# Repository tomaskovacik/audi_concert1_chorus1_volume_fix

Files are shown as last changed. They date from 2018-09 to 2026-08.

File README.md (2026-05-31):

> ## ⚠️ v2.0.0 — Important notice
>
> **Firmware v2.0.0 is only suitable for HWv5 boards.** It will NOT work correctly on older hardware revisions (v1–v4).
>
> This release is currently **under real-life / daily-use testing**. If you experience issues, please open a [GitHub issue](https://github.com/tomaskovacik/audi_concert1_chorus1_volume_fix/issues).
>
> ### What changed in v2.0.0 (not in release notes — no PRs were used)
>
> - **Switched to official STMicroelectronics STM32 Arduino core** (replaces Roger Clark's libmaple/stm32duino community core)
> - **Hardware SPI** used for front-panel communication (via STM32 core SPI peripheral)
> - **FlexWire** software I2C library used for TDA7342 volume chip communication on PB10/PB11  
>   (STM32F103C6 has only one I2C peripheral; hardware I2C2 does not exist on this chip)
> - **Persistent config** saved to last flash page (volume level, GALA, TA) — replaces EEPROM emulation from older cores
> - **GALA** (speed-dependent volume) support via VSS pulse timing on PB5
> - **CI** updated to build and release firmware binary automatically on git tags

Software and hardware to fix volume problem on audi concert1/chorus1 units made by blaupunkt. More about this problem in [this](https://github.com/tomaskovacik/audi_concert1_chorus1_volume_fix/wiki/Problem-of-Some-AUDI-Chorus-and-AUDI-Concert-Autoradio-Models,-or-%22Delayed-Action-Mine%22-from-Blaupunkt-Company) wiki page which is copy from [here](https://web.archive.org/web/20071017195907/http://erta.ru/review/chorus-problem_eng.shtml).

#### Compatible radios:

These are 100% compatible, manufactured by Blaupunkt:
```
Audi Chorus - 7 646 243 380 (4B0 035 152)
Audi Chorus A8 - 7 647 243 380
Audi Concert - 7 646 248 380 (4B0 035 186)
Audi Concert A8 - 7 647 248 380 (4D0 035 186A)
Audi Concert Navi - 7 647 249 380 (4B0 035 186B)
AUDI	CONCERT TT AUZ1Z3	7 648 244 380 (4B0 035 186D)
```
Maybe for these, drop me a message with pictures of radio from outside and inside, and I can check if your radio is compatible with this module:
```
AUDI	CHORUS A3	7 640 251 380
AUDI	CHORUS A8	7 648 243 380
AUDI	CHORUS AUZ1Z2	7 647 245 380   4B0 035 152A
AUDI	CHORUS M4 AUZ1Z2	7 648 245 380   4B0 035 152B
AUDI	CHORUS M4 AUZ1Z2	7 648 245 380   4B0 035 152B
AUDI	CONCERT A8	7 648 248 380
AUDI	CONCERT M4 AUZ1Z3	7 648 247 380   4B0 035 186C
```
#### Not compatible radios

Audio Concert made by Panasonic/Matsushita (8L0 035 186A, possible other codes ).This radio from this manufacturer did not have problems with volume (if it has, the problem is in volume rotary encoder)

There are other radios manufactured by Blaupunkt called Audi Concert Plus, which are not compatible:
```
AUDI	CONCERT PLUS AUZ1Z3	7 649 246 380   4B0 035 186E
AUDI	CONCERT PLUS A8 AUZ1Z3	7 649 249 380   4D0 035 186F
```
These use a different design and so are not compatible with this module. I never read that these radios did have a volume problem. If there is one then it is most likely a problem with volume rotary encoder.

#### Issues
Known issues <a href="https://github.com/tomaskovacik/audi_concert1_chorus1_volume_fix/issues">are here</a>

#### Video
Module in action: 

#### Schematics:

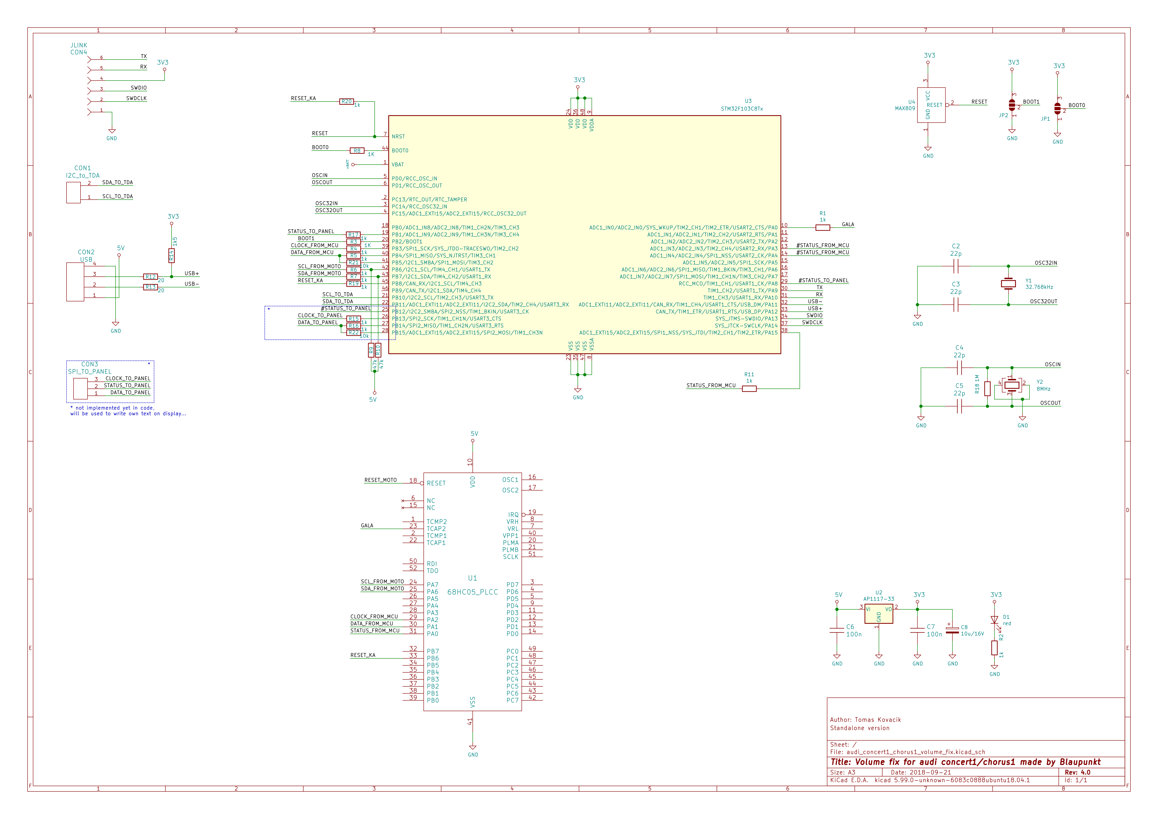
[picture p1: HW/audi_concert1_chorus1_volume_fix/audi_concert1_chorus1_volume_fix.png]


Schematics in <a href="https://github.com/tomaskovacik/audi_concert1_chorus1_volume_fix/blob/master/HW/audi_concert1_chorus1_volume_fix/audi_concert1_chorus1_volume_fix.pdf">pdf</a>.

Assemble plan for latest v5 is <a href="https://tomaskovacik.github.io/audi_concert1_chorus1_volume_fix/HW/audi_concert1_chorus1_volume_fix/bom_v5/ibom.html">here</a>. Components with value prefi NP_ are not required (not populated). These are there for future features. 1k_GALA resistor has to be populated if SW with <a href="https://github.com/tomaskovacik/audi_concert1_chorus1_volume_fix/blob/gala/SW/audi_volume_fix_stm32/audi_volume_fix_stm32.ino">gala</a> support is used (SW from gala branch). AP for old v1 hw is <a href="https://raw.githubusercontent.com/tomaskovacik/audi_concert1_chorus1_volume_fix/master/HW/audi_concert1_chorus1_volume_fix/assemble_plan1_0.png">here</a>.

Pictures of finished product:

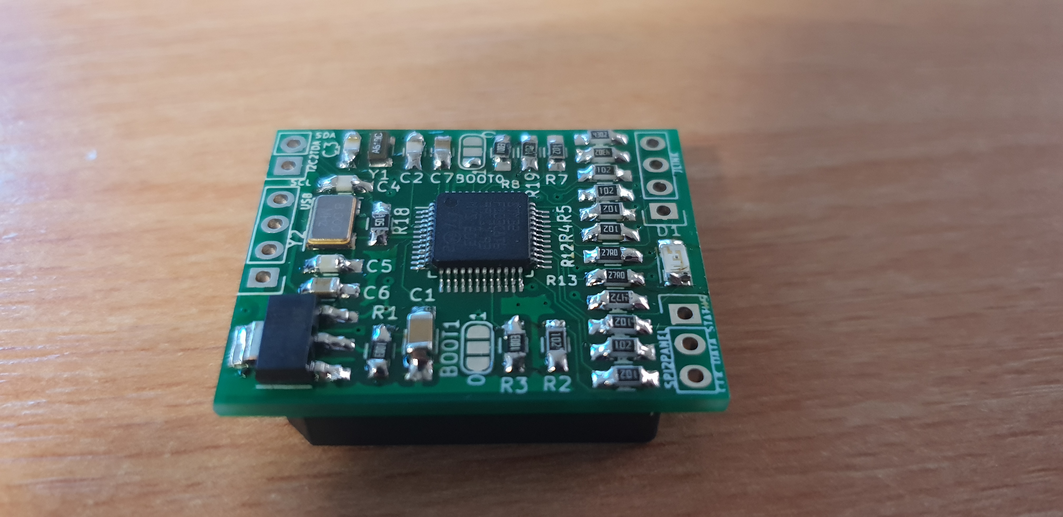
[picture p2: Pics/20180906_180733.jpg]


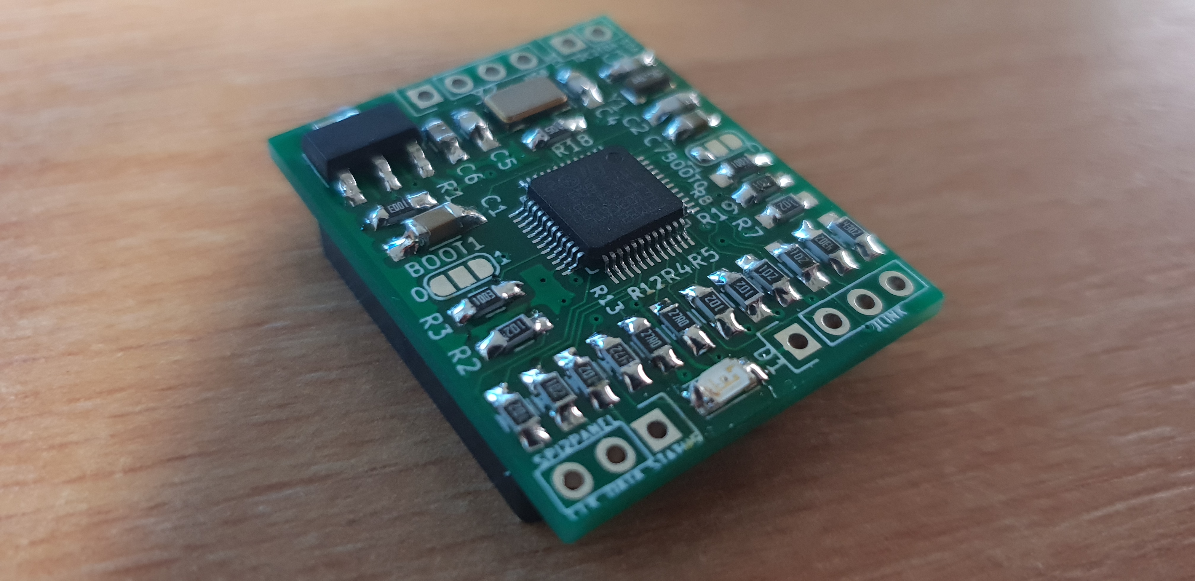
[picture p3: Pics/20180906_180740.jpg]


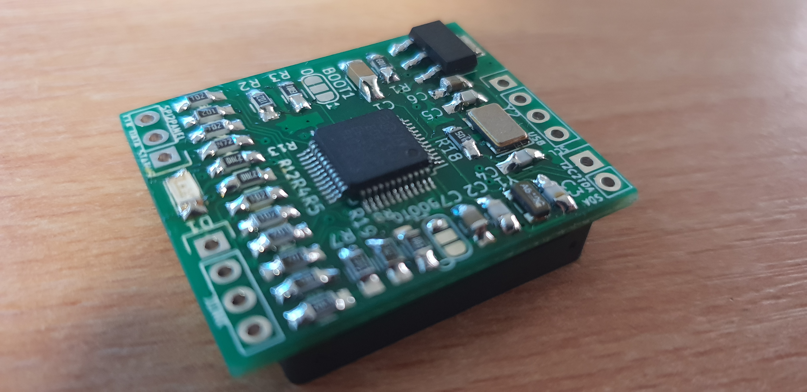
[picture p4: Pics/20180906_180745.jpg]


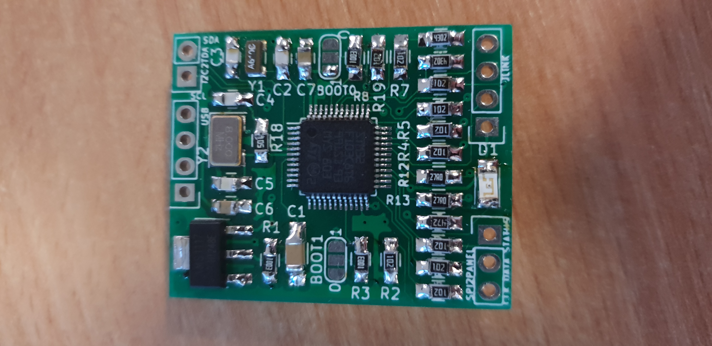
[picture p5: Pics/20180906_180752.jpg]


Bottom side, with PLCC52 socket, inside part of pastic need to be cut:

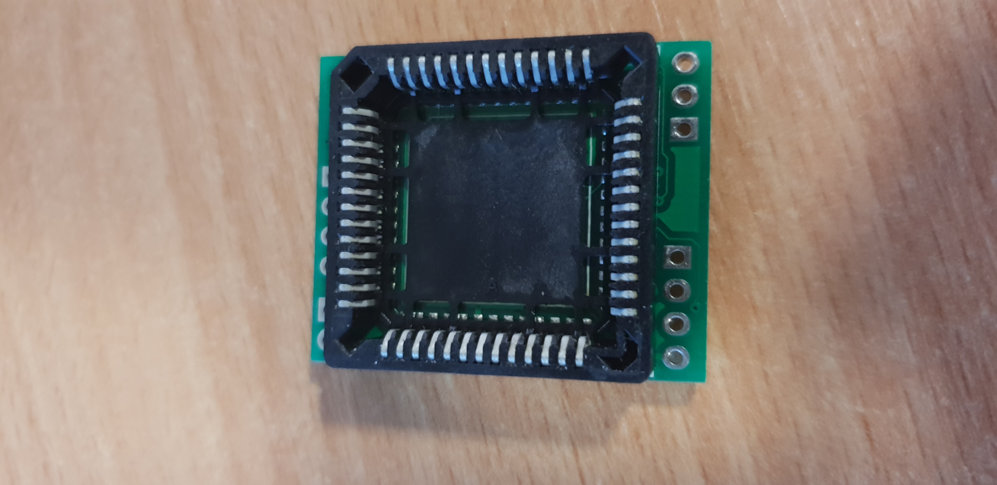
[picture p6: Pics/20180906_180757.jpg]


Upper side, with comments to sockets

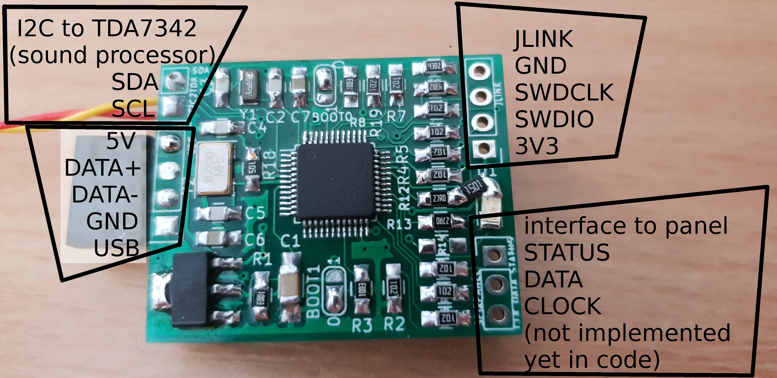
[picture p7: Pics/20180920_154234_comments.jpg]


How to wire it (currently without intefacing with front pannel)

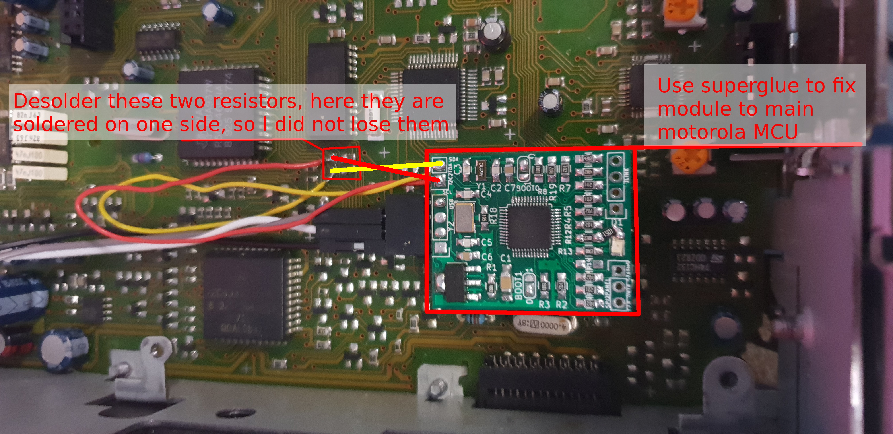
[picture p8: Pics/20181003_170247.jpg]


# COPYING

Everything is under GPLv3

# CONTRIBUTION

Contributions are welcome

# PCBs

PCBs are on sale also as whole product, kitt (PCB, soldered crystals, unsoldered preprogramed IC, pasives,PLCC52 socket)



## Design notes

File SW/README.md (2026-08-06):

# Firmware — Audi Concert1 / Chorus1 volume fix

STM32F103C6-based firmware that fixes the volume problem on Blaupunkt-made
Audi Concert 1 / Chorus 1 head units.  Target hardware: **HWv5**.

---

## Branches

| Branch | Description |
|---|---|
| `master` | Stable HWv5 firmware — passive SPI sniffer, GALA, flash config, serial decoder |
| `dual-spi-panel-bridge` | **WIP** — HWv5 man-in-the-middle bridge: SPI1 slave (MCU side) + SPI2 master (panel side); STM32 intercepts and forwards packets in both directions. Activate with `#define HWV5_BRIDGE`; omit for passive-sniff fallback. |
| `feature/eeprom-gala-isr-STM32CORE-sleep` | Deep sleep on displayRESET LOW — kept for reference, no real benefit with current HW |

---

## Building and flashing

### Dependencies

- Arduino IDE install at `/opt/arduino-nightly/`
- **Official STMicroelectronics STM32 core 2.12+** installed via Arduino Boards Manager:
  - Board URL: `https://github.com/stm32duino/BoardManagerFiles/raw/main/package_stmicroelectronics_index.json`
  - Package: `STMicroelectronics:stm32` — select board **Generic STM32F1 series → BluePill F103C6**
  - Tools installed automatically: `xpack-arm-none-eabi-gcc 14.2.1-1.1`, `STM32Tools 2.4.0`, `xpack-openocd 0.12.0-6`
- **FlexWire** library (software I2C) — install via Arduino Library Manager or from source

### Build targets

```bash
cd SW/audi_volume_fix_stm32
make          # compile only
make upload   # compile + flash via ST-Link (OpenOCD)
make serial   # open serial monitor (115200 baud)
make clean    # remove build artefacts
```

### Flashing

Flashing uses **OpenOCD** (bundled with the official core) via ST-Link:

```bash
make upload
```

No separate `st-flash` installation needed.

---

## Serial decoder (`SW/decoder.py`)

Reads the firmware's serial output and prints human-readable labels.

```bash
# From USB serial port (default 115200 baud):
python3 decoder.py /dev/ttyUSB0

# Custom baud:
python3 decoder.py /dev/ttyUSB0 9600

# Pipe from file or socat:
python3 decoder.py --stdin < log.txt

# Append raw hex [XX XX ...] to every decoded line:
python3 decoder.py --debug /dev/ttyUSB0
python3 decoder.py --debug --stdin
```

Output prefixes:

| Prefix | Colour | Meaning |
|---|---|---|
| `SPI` | Yellow | Front-panel → MCU SPI packet (decoded) |
| `BTN` | Red | Button / knob event |
| `TDA` | Green | STM32 → TDA7342 I2C command (decoded) |

---

## Configuration (`feature/eeprom-gala-isr-STM32CORE`)

### Stored values

Configuration is saved in the **last 1 KB page of STM32 flash** (`0x8007C00`).
Three values are persisted:

| Field | Range | Default | Meaning |
|---|---|---|---|
| `vol` | 1–5 | 3 | Start volume level at power-on |
| `gala` | 0–5 | 0 | GALA speed-volume aggressiveness (0 = off) |
| `ta` | 1–5 | 3 | TA (traffic announcement) level |

The page is protected by 3 magic bytes and a CRC (`vol+gala+ta`).
After a CRC pass each field is range-checked; out-of-range fields fall
back to their default individually (guards against partial flash corruption).

### Start volume (`vol`)

`vol` is a **fixed level index**, not a relative offset.  It maps to an
absolute TDA7342 register value via a lookup table:

| `vol` | I2C hex | Approx. level |
|---|---|---|
| 1 | `0x56` | quietest |
| 2 | `0x52` | |
| 3 | `0x4E` | default |
| 4 | `0x4A` | |
| 5 | `0x46` | loudest |

Each step is 4 register counts ≈ **2 dB**.

### GALA speed-volume (`gala`)

GALA (*Geschwindigkeitsabhängige Lautstärkeautomatik* — speed-dependent automatic
volume) automatically raises the volume as speed increases to compensate for rising
road and wind noise, keeping perceived audio level consistent.

| Level | Sensitivity | Description |
|---|---|---|
| `0` | Off | Volume stays exactly where you set it — GALA disabled |
| `1` | Lowest | Subtle boost; only noticeable at high highway speeds |
| `2` | Low | Mild adjustment for relaxed highway driving |
| `3` | Medium | Factory sweet spot for a stock Audi cabin; smooth steps with normal acceleration |
| `4` | High | More aggressive; volume rises at lower speed thresholds |
| `5` | Highest | Aggressively boosts volume starting at low speeds |

When `gala > 0` the firmware measures a VSS (vehicle speed signal) pulse width on
**PB5** (TIM3_CH2, tied with PB4/TIM3_CH1). Speed is derived from the pulse half-period:

```
speed_km/h = 1 000 000 / (2 × avg_pulse_width_µs)
```

An 8-sample rolling average suppresses µs-level jitter.

GALA level controls the base speed threshold at which volume starts rising:

| `gala` | Base threshold |
|---|---|
| 1 | 100 km/h |
| 2 | 85 km/h |
| 3 | 70 km/h |
| 4 | 55 km/h |
| 5 | 40 km/h |

Above the base threshold volume steps **up** by 1 and loudness steps **down**
every additional 30 km/h band.  Slowing down reverses the corrections.

Hardware: BC558 PNP high-side driver on the radio PCB drives the GALA line.
STM32 PB5 is connected in parallel with HC05 pin 23 via a 1 kΩ series resistor.
`INPUT_PULLDOWN` is used so the pin reads LOW cleanly when the transistor is OFF.

### Setting config via serial commands

With `USE_SERIAL` enabled, send commands over UART1 (115200 baud):

| Command | Effect |
|---|---|
| `s1` … `s5` | Set start volume level |
| `g0` … `g5` | Set GALA level (0 = off) |
| `w` | Save current config to flash |

### Setting config via radio menu (display auto-save)

The firmware sniffs `0x9A 0x58` display packets sent by the radio when the
user navigates the **settings menu** (accessed with the TP button).
Config is saved to flash automatically as the user scrolls:

| Radio display | Saved value |
|---|---|
| `VOL  1` … `VOL  5` | `vol` = 1–5 |
| `GALA 1` … `GALA 5` | `gala` = 1–5 |
| `GALA OFF` | `gala` = 0 |
| `TA 1` … `TA 5` | `ta` = 1–5 |

### Debug serial output

When `USE_SERIAL` is defined, key events print with these prefixes:

| Prefix | When |
|---|---|
| `CFG_LOAD: vol=X gala=X ta=X` | Config read from flash at startup |
| `CFG_PANEL: vol/gala/ta=X` | Value parsed from radio display packet |
| `CFG_SAVE: OK/FAIL vol=X gala=X ta=X` | Flash write result |
| `GALA_SPEED: prev->new km/h base_thr=X` | Speed change detected |
| `GALA_VOL: UP/DOWN band=X thr=X vol=0xXX` | Volume step applied |
| `GALA_LOUD: UP/DOWN band=X thr=X loud=0xXX` | Loudness step applied |

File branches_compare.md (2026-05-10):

# Branch Comparison Summary

## `devel` vs `master` — Branch Comparison

The `devel` branch is ahead of `master` with significant changes to `SW/audi_volume_fix_stm32/audi_volume_fix_stm32.ino` and one new binary file.

## 📁 Files Changed

- `SW/audi_volume_fix_stm32/audi_volume_fix_stm32.ino` — Major changes (details below)
- `gala_on_V1.png` (new file) — A new image added (likely documentation for GALA on V1 board)

## 🔧 Key Code Changes in `devel`

### 1. EEPROM Support Added

- Includes `<EEPROM.h>` and defines EEPROM layout (`EEPROM_PAGE0_BASE`, `EEPROM_PAGE1_BASE`, `EEPROM_PAGE_SIZE`)
- New EEPROM keys: `EEPROM_GALA`, `EEPROM_VOL`, `EEPROM_TA`, `EEPROM_CR1`–`CR4`
- New functions: `checkEEPROM()`, `getGalaEeprom()`, `getVolEeprom()`, `getTaEeprom()`, `saveGalaEeprom()`, `saveVolEeprom()`, `saveTaEeprom()`
- Settings (GALA, VOL, TA) are now persisted across power cycles

### 2. GALA (Speed-Dependent Volume) Feature

- New GALA pin defined (`PA14` for V1 board, `PA0` for V2)
- Interrupt-driven speed sensing using Timer2 — `galaRising()` / `galaFalling()` ISRs
- Speed is calculated from pulse timing (`captime`)
- Volume and loudness are automatically adjusted as speed increases/decreases in 30 km/h steps (up to 300+ km/h range)
- `getGalaStartSpeed()` computes the activation threshold from EEPROM

### 3. `set_volume()` renamed to `send_volume()`

- `set_loudness()` now only calculates the loudness value
- New `send_loudness()` function handles sending it over I²C
- Calls to `set_volume()` replaced throughout with `send_volume()` + `send_loudness()` pairs
- Volume packet sending logic refactored (removed duplicate `set_loudness()` calls inside the loop)

### 4. Start Volume from EEPROM

- `start_volume` now initialized from `setStartVolumeFromEeprom()` (maps 1–5 → hex values)
- Was hardcoded `0x82`; now defaults to `0x4E`
- Also re-applied on display reset event

### 5. I²C Dump Mode Improvements

- `dumpI2cDataAndDoNotFix` renamed to `dumpI2cData` — it's now independent from the fix logic (both can run simultaneously)
- `dump_i2c_data()` output format improved: `I2c data: [ xx xx ]`

### 6. Display Data Parsing for Settings

- Detects VOL/TA/GALA settings displayed on the panel and saves them to EEPROM automatically
  - e.g., `"VOL  X  "` → saves volume level, `"GALA X  "` → saves GALA setting

### 7. Code Style / Minor Fixes

- Fixed indentation of several `case` labels in `decode_button_push()`
- Miscellaneous whitespace and comment cleanup

## Summary Table

| Feature | `master` | `devel` |
|---|---|---|
| EEPROM persistence | ❌ | ✅ |
| GALA (speed-adaptive volume) | ❌ | ✅ |
| Start volume | Hardcoded `0x82` | From EEPROM (`0x4E` default) |
| Loudness sending | Inside `set_loudness()` | Separate `send_loudness()` |
| Dump mode decoupled from fix | ❌ | ✅ |
| Settings saved from display | ❌ | ✅ |

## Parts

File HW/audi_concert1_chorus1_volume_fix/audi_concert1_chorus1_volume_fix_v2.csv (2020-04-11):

Id | Designator | Package | Quantity | Designation | Supplier and ref
1 | R14 | R_0805_HandSoldering | 1 | 1k5
2 | R8,R3 | R_0805_HandSoldering | 2 | 100k
3 | R1,R20,R19,R17,R16,R15,R6,R5,R4,R11,R2,R7 | R_0805_HandSoldering | 12 | 1k
4 | U4 | SOT-23 | 1 | MAX809
5 | CON4 | Pin_Header_Straight_1x06 | 1 | JLINK
6 | BOOT0,BOOT1 | SolderJumper-3_P1.3mm_Open_RoundedPad1.0x1.5mm_NumberLabels | 2 | SolderJumper_3_Open
7 | CON3 | Pin_Header_Straight_1x03 | 1 | SPI_TO_PANEL
8 | CON2 | Pin_Header_Straight_1x04 | 1 | USB
9 | Y2 | Crystal_SMD_5032-4pin_5.0x3.2mm | 1 | 8MHz
10 | Y1 | Crystal_SMD_3215-2pin_3.2x1.5mm | 1 | 32.768kHz
11 | R18 | R_0805_HandSoldering | 1 | 1M
12 | R13,R12 | R_0805_HandSoldering | 2 | 20
13 | D1 | LED-1206 | 1 | LED
14 | CON1 | Pin_Header_Straight_1x02 | 1 | I2C_to_TDA
15 | C7,C6 | C_0805_HandSoldering | 2 | 100n
16 | C5,C4,C3,C2 | C_0805_HandSoldering | 4 | 22p
17 | U1 | PLCC-52_mirrored | 1 | 68HC05_PLCC
18 | U2 | AB2_SOT223 | 1 | AP1117-33
19 | R10,R9 | R_0805_HandSoldering | 2 | 47k
20 | C8 | TantalC_SizeA_EIA-3216_HandSoldering | 1 | 10u/16V
21 | U3 | LQFP-48_7x7mm_Pitch0.5mm | 1 | STM32F103C8Tx

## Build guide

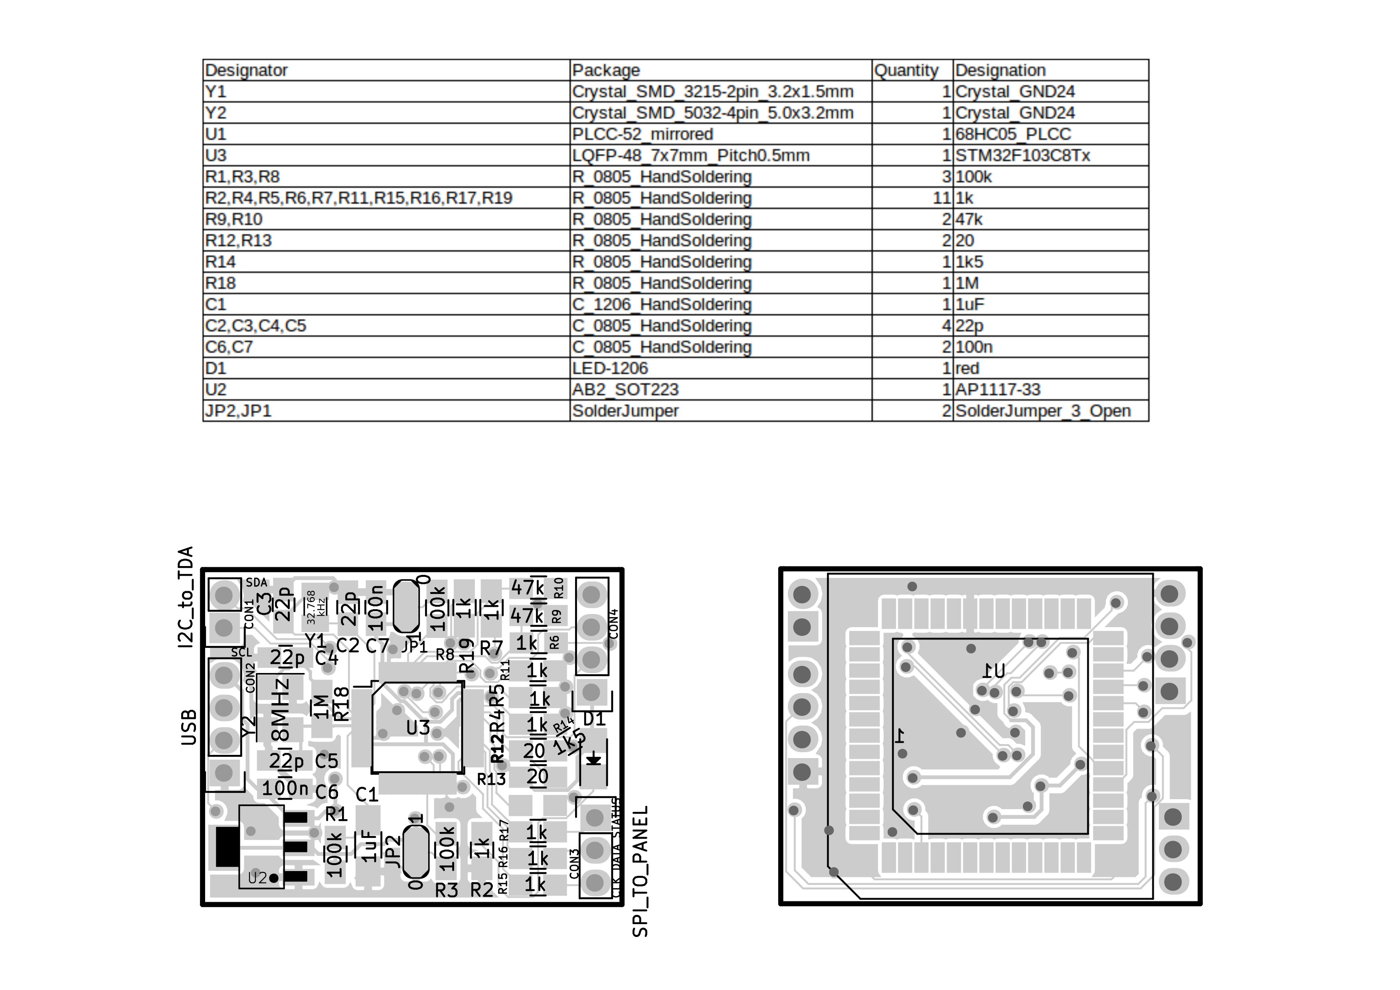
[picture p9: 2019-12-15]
HW/audi_concert1_chorus1_volume_fix/assemble_plan1_0.png

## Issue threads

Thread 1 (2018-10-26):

after restart of car treble and bass level is not set properly.

tomaskovacik, 2018-10-26:
after restart of car, looks like something did not catch up.... treble and bass level is not set properly, this need to by probably investigated more complexly to realize if we are sending something to soon, to fast
  or we just missing capture of something or we catch everything and just forget to send it to TDA???

tomaskovacik, 2019-03-22:
looks like fixed by b7195835907241808e6d238cddf0f1e86493aa1a

tomaskovacik, 2019-03-22:
on my concert it is still problem, but probably problem of MCU:

Reset HIGH
 uknown25

Speaker Attenuator left front: -3.75dB
Speaker Attenuator left rear: 0.00dB
Speaker Attenuator right front: -3.75dB
Speaker Attenuator left rear: 0.00dB
Bass: 0dB, Trebble: 0dB
Mute: Soft Mute with fast slope (I = Imax)
Zero Crossing Mute Off
160mV ZC Window Threshold (WIN = 00)
Symmetrical Bass Cut
Input selector: CD selected (0dB diferential input gain (IN3))

Memory: 0

LEDS:

display clear

Memory: 0

LEDS:
MODE
display clear
 uknown0

CD2 TR4
CD2 TR4
CD2 TR4
CD81 TR4
CD2 TR4
Loudness:  - 16.2500000000dB
Loudness:  - 15.0000000000dB
Loudness:  - 13.7500000000dB
Loudness:  - 12.5000000000dB
Loudness:  - 11.2500000000dB
Loudness:  - 10.0000000000dB
Loudness:  - 8.7500000000dB
Loudness:  - 7.5000000000dB
volume -59.06dB ( FD )
volume -58.43dB ( FB )
volume -57.81dB ( F9 )
volume -57.18dB ( F7 )
volume -56.56dB ( F5 )
volume -55.93dB ( F3 )
volume -55.31dB ( F1 )
volume -54.68dB ( EF )
volume -54.06dB ( ED )
volume -53.43dB ( EB )
volume -52.81dB ( E9 )
volume -52.18dB ( E7 )
volume -51.56dB ( E5 )
volume -50.93dB ( E3 )
volume -50.31dB ( E1 )
volume -49.68dB ( DF )
volume -49.06dB ( DD )
volume -48.43dB ( DB )
volume -47.81dB ( D9 )
volume -47.18dB ( D7 )
volume -46.56dB ( D5 )
volume -45.93dB ( D3 )
volume -45.31dB ( D1 )
volume -44.68dB ( CF )
volume -44.06dB ( CD )
volume -43.43dB ( CB )
volume -42.81dB ( C9 )
volume -42.18dB ( C7 )
volume -41.56dB ( C5 )
volume -40.93dB ( C3 )
volume -40.31dB ( C1 )
volume -39.68dB ( BF )
volume -39.06dB ( BD )
volume -38.43dB ( BB )
volume -37.81dB ( B9 )
volume -37.18dB ( B7 )
volume -36.56dB ( B5 )
volume -35.93dB ( B3 )
volume -35.31dB ( B1 )
volume -34.68dB ( AF )
volume -34.06dB ( AD )
volume -33.43dB ( AB )
volume -32.81dB ( A9 )
volume -32.18dB ( A7 )
volume -31.56dB ( A5 )
volume -30.93dB ( A3 )
volume -30.31dB ( A1 )
volume -29.68dB ( 9F )
volume -29.06dB ( 9D )
volume -28.43dB ( 9B )
volume -27.81dB ( 99 )
volume -27.18dB ( 97 )
volume -26.56dB ( 95 )
volume -25.93dB ( 93 )
volume -25.31dB ( 91 )
volume -24.68dB ( 8F )
volume -24.06dB ( 8D )
volume -23.43dB ( 8B )
volume -22.81dB ( 89 )
volume -22.18dB ( 87 )
volume -21.56dB ( 85 )
volume -20.93dB ( 83 )
volume -20.31dB ( 81 )
volume -19.68dB ( 7F )
volume -19.06dB ( 7D )
volume -18.43dB ( 7B )
volume -17.81dB ( 79 )
volume -17.18dB ( 77 )
volume -16.56dB ( 75 )
volume -15.93dB ( 73 )
volume -15.31dB ( 71 )
volume -14.68dB ( 6F )
volume -14.06dB ( 6D )
volume -13.43dB ( 6B )
volume -12.81dB ( 69 )
volume -12.18dB ( 67 )
volume -11.56dB ( 65 )
volume -10.93dB ( 63 )
volume -10.31dB ( 61 )
volume -9.68dB ( 5F )
volume -9.06dB ( 5D )
volume -8.43dB ( 5B )
volume -7.81dB ( 59 )
volume -7.18dB ( 57 )
volume -6.56dB ( 55 )
volume -5.93dB ( 53 )
volume -5.31dB ( 51 )
volume -4.68dB ( 4F )
volume -4.06dB ( 4D )
volume -3.43dB ( 4B )
volume -2.81dB ( 49 )
volume -2.18dB ( 47 )
volume -1.56dB ( 45 )
volume -0.93dB ( 43 )
volume -0.31dB ( 41 )
volume 0.32dB ( 3F )
volume 0.94dB ( 3D )
volume 1.57dB ( 3B )
volume 2.19dB ( 39 )
volume 2.50dB ( 38 )
Mute: Zero Crossing Mute Off
160mV ZC Window Threshold (WIN = 00)
Symmetrical Bass Cut
Speaker Attenuator left front: -3.75dB
Speaker Attenuator left rear: 0.00dB
Speaker Attenuator right front: -3.75dB
Speaker Attenuator left rear: 0.00dB
Bass: 0dB, Trebble: 0dB
Loudness:  - 8.7500000000dB
Loudness:  - 10.0000000000dB
Loudness:  - 11.2500000000dB
Loudness:  - 12.5000000000dB
Loudness:  - 13.7500000000dB
Loudness:  - 15.0000000000dB
Loudness:  - 16.2500000000dB
Loudness:  - 17.5000000000dB
volume 1.88dB ( 3A )
volume 1.25dB ( 3C )
volume 0.63dB ( 3E )
volume 0.00dB ( 40 )
volume -0.62dB ( 42 )
volume -1.25dB ( 44 )
volume -1.87dB ( 46 )
volume -2.50dB ( 48 )
volume -3.12dB ( 4A )
volume -3.75dB ( 4C )
volume -4.37dB ( 4E )
volume -5.00dB ( 50 )
volume -5.62dB ( 52 )
volume -6.25dB ( 54 )
volume -6.87dB ( 56 )
volume -7.50dB ( 58 )
volume -8.12dB ( 5A )
volume -8.75dB ( 5C )
volume -9.37dB ( 5E )
volume -10.00dB ( 60 )
volume -10.62dB ( 62 )
volume -11.25dB ( 64 )
volume -11.87dB ( 66 )
volume -12.50dB ( 68 )
volume -13.12dB ( 6A )
volume -13.75dB ( 6C )
volume -14.37dB ( 6E )
volume -15.00dB ( 70 )
volume -15.62dB ( 72 )
volume -16.25dB ( 74 )
volume -16.87dB ( 76 )
volume -17.50dB ( 78 )
volume -18.12dB ( 7A )
volume -18.75dB ( 7C )
volume -19.37dB ( 7E )
volume -20.00dB ( 80 )
volume -20.62dB ( 82 )
volume -21.25dB ( 84 )
volume -21.87dB ( 86 )
volume -22.50dB ( 88 )
volume -23.12dB ( 8A )
volume -23.75dB ( 8C )
volume -24.37dB ( 8E )
volume -25.00dB ( 90 )
volume -25.62dB ( 92 )
volume -26.25dB ( 94 )
volume -26.87dB ( 96 )
volume -27.50dB ( 98 )
volume -28.12dB ( 9A )
volume -28.75dB ( 9C )
volume -29.37dB ( 9E )
volume -30.00dB ( A0 )
volume -30.62dB ( A2 )
volume -31.25dB ( A4 )
volume -31.87dB ( A6 )
volume -32.50dB ( A8 )
volume -33.12dB ( AA )
volume -33.75dB ( AC )
volume -34.37dB ( AE )
volume -35.00dB ( B0 )
volume -35.62dB ( B2 )
volume -36.25dB ( B4 )
volume -36.87dB ( B6 )
volume -37.50dB ( B8 )
volume -38.12dB ( BA )
volume -38.75dB ( BC )
volume -39.37dB ( BE )
volume -40.00dB ( C0 )
volume -40.62dB ( C2 )
volume -41.25dB ( C4 )
volume -41.87dB ( C6 )
volume -42.50dB ( C8 )
volume -43.12dB ( CA )
volume -43.75dB ( CC )
volume -44.37dB ( CE )
volume -45.00dB ( D0 )
volume -45.62dB ( D2 )
volume -46.25dB ( D4 )
volume -46.87dB ( D6 )
volume -47.50dB ( D8 )
volume -48.12dB ( DA )
volume -48.75dB ( DC )
volume -49.37dB ( DE )
volume -50.00dB ( E0 )
volume -50.62dB ( E2 )
volume -51.25dB ( E4 )
volume -51.87dB ( E6 )
volume -52.50dB ( E8 )
volume -53.12dB ( EA )
volume -53.75dB ( EC )
volume -54.37dB ( EE )
volume -55.00dB ( F0 )
volume -55.62dB ( F2 )
volume -56.25dB ( F4 )
volume -56.87dB ( F6 )
volume -57.50dB ( F8 )
volume -58.12dB ( FA )
volume -58.75dB ( FC )
volume -59.37dB ( FE )
volume -59.68dB ( FF )
Mute: Soft Mute with fast slope (I = Imax)
Zero Crossing Mute Off
160mV ZC Window Threshold (WIN = 00)
Symmetrical Bass Cut
CD2 TR4
Loudness:  - 16.2500000000dB
Loudness:  - 15.0000000000dB
Loudness:  - 13.7500000000dB
Loudness:  - 12.5000000000dB
Loudness:  - 11.2500000000dB
Loudness:  - 10.0000000000dB
Loudness:  - 8.7500000000dB
Loudness:  - 7.5000000000dB
volume -59.06dB ( FD )
volume -58.43dB ( FB )
volume -57.81dB ( F9 )
volume -57.18dB ( F7 )
volume -56.56dB ( F5 )
volume -55.93dB ( F3 )
volume -55.31dB ( F1 )
volume -54.68dB ( EF )
volume -54.06dB ( ED )
volume -53.43dB ( EB )
volume -52.81dB ( E9 )
volume -52.18dB ( E7 )
volume -51.56dB ( E5 )
volume -50.93dB ( E3 )
volume -50.31dB ( E1 )
volume -49.68dB ( DF )
volume -49.06dB ( DD )
volume -48.43dB ( DB )
volume -47.81dB ( D9 )
volume -47.18dB ( D7 )
volume -46.56dB ( D5 )
volume -45.93dB ( D3 )
volume -45.31dB ( D1 )
volume -44.68dB ( CF )
volume -44.06dB ( CD )
volume -43.43dB ( CB )
volume -42.81dB ( C9 )
volume -42.18dB ( C7 )
volume -41.56dB ( C5 )
volume -40.93dB ( C3 )
volume -40.31dB ( C1 )
volume -39.68dB ( BF )
volume -39.06dB ( BD )
volume -38.43dB ( BB )
volume -37.81dB ( B9 )
volume -37.18dB ( B7 )
volume -36.56dB ( B5 )
volume -35.93dB ( B3 )
volume -35.31dB ( B1 )
volume -34.68dB ( AF )
volume -34.06dB ( AD )
volume -33.43dB ( AB )
volume -32.81dB ( A9 )
volume -32.18dB ( A7 )
volume -31.56dB ( A5 )
volume -30.93dB ( A3 )
volume -30.31dB ( A1 )
volume -29.68dB ( 9F )
volume -29.06dB ( 9D )
volume -28.43dB ( 9B )
volume -27.81dB ( 99 )
volume -27.18dB ( 97 )
volume -26.56dB ( 95 )
volume -25.93dB ( 93 )
volume -25.31dB ( 91 )
volume -24.68dB ( 8F )
volume -24.06dB ( 8D )
volume -23.43dB ( 8B )
volume -22.81dB ( 89 )
volume -22.18dB ( 87 )
volume -21.56dB ( 85 )
volume -20.93dB ( 83 )
volume -20.31dB ( 81 )
volume -19.68dB ( 7F )
volume -19.06dB ( 7D )
volume -18.43dB ( 7B )
volume -17.81dB ( 79 )
volume -17.18dB ( 77 )
volume -16.56dB ( 75 )
volume -15.93dB ( 73 )
volume -15.31dB ( 71 )
volume -14.68dB ( 6F )
volume -14.06dB ( 6D )
volume -13.43dB ( 6B )
volume -12.81dB ( 69 )
volume -12.18dB ( 67 )
volume -11.56dB ( 65 )
volume -10.93dB ( 63 )
volume -10.31dB ( 61 )
volume -9.68dB ( 5F )
volume -9.06dB ( 5D )
volume -8.43dB ( 5B )
volume -7.81dB ( 59 )
volume -7.18dB ( 57 )
volume -6.56dB ( 55 )
volume -5.93dB ( 53 )
volume -5.31dB ( 51 )
volume -4.68dB ( 4F )
volume -4.06dB ( 4D )
volume -3.43dB ( 4B )
volume -2.81dB ( 49 )
volume -2.18dB ( 47 )
volume -1.56dB ( 45 )
volume -0.93dB ( 43 )
volume -0.31dB ( 41 )
volume 0.32dB ( 3F )
volume 0.94dB ( 3D )
volume 1.57dB ( 3B )
volume 2.19dB ( 39 )
volume 2.50dB ( 38 )
Mute: Zero Crossing Mute Off
160mV ZC Window Threshold (WIN = 00)
Symmetrical Bass Cut
CD2 TR4

selecting one of bass/trebble fix it:

 TREB

TRE 0
TRE 0
button release

 Knob +

Bass: 2dB, Trebble: 2dB
Speaker Attenuator left front: -3.75dB
Speaker Attenuator left rear: 0.00dB
Speaker Attenuator right front: -3.75dB
Speaker Attenuator left rear: 0.00dB
TRE +1
CD2 TR4

tomaskovacik, 2019-03-25:
looks like this is problem only in cdchanger mode ... need more testing of this theory

tomaskovacik, 2019-03-27:
if main MCU has stored volume lower then some specific value it automaticaly set bass/trebble, then even pushing the FAD/BASS/TREBBLE/BALL has no efect, this can be problem with my MCU

tomaskovacik, 2019-04-07:
shoud be fixed in eea99ec072d7f5a646a6e557dd1f4ac682dce4f3

tomaskovacik, 2021-11-06:
using fastboot bootloader fix this for sure

Closed 2019-04-07.

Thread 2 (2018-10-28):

switching to TP did not work

tomaskovacik, 2018-10-28:
automatic switch to TP while playing from cd changer did not work , nothing come from speakers.
Disabling TP bring volume back where it should be.

tomaskovacik, 2018-10-31:
- it may be just cose I have emulator without thi fix: https://github.com/tomaskovacik/vwcdavr/issues/8

tomaskovacik, 2019-02-15:
working fine

Closed 2019-02-15.

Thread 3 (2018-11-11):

create logic to analyze if mute packet is legit

tomaskovacik, 2018-11-11:
create logic to analyze if mute packet is legit or it should be discarded as false mute if buggy mcu set volume to zero = muted audio

tomaskovacik, 2018-11-11:
this is annoying but better then buggy mcu cose radio neve goes to max volume randomly

kaalis, 2019-01-10:
Hello, is there approx. time when this chorus1 volume fix hardware could appear in your tindie account? Could it be working for the same age concert1?

tomaskovacik, 2019-03-26:
still not sure, current devel branch can fix it, if anyone has this problem please test it.

current logic is simple:
mute packet is legit always (set to 1 when any data are send on bus to front panel) but in volume change mode fired by turning of knob, here we set it to 0

 I'm still trying to avoind marking every scenario when mute packet is legit, like seach FM/AM, switch station memo, TP info, switching tape/radio/cd .....

tomaskovacik, 2019-03-26:
lets analyze data and create other logic:
currently if mute packet is receive, we set volume to 0, mute, do what ever radio wanna do and then unmute and restore volume, so change it to mute only if action which required more is called:
- switch input.
    - in packet to change input is grabed, set volume to 0, all set_volume(), set_mute() and then send i2c data with input selection, then do unmute when MCU Send it.
- search (fm/am mode)
   - in this case mcu only call mute, then start search, we can mute based on data displayed on panel
- telefon
  - same as search
- TP info
  - this is standard switch input
- TAPE mode
  - FR/FF - we can mute based on pushed button
  - this need to be investigated, I do not know what exacly need to be done here, mostly, when reverse, eject is called from front panel, we can do what mcu did, problem is when autoreverse is used, in this case we did not have option how to know it before slave did switch sides, because we do not hijacked this bus
- CD mode
   - switch CD/track - we can change based on pushed button
   - FR/FF - we can change based on pushed button

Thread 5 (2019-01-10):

Hello, is there approx. time when this chorus1 volume fix hardware could appear in your tindie account? Could it be working for the same age concert1?

tomaskovacik, 2019-01-10:
Hello, is there approx. time when this chorus1 volume fix hardware could appear in your tindie account? Could it be working for the same age concert1?

_Originally posted by @kaalis in https://github.com/tomaskovacik/audi_concert1_chorus1_volume_fix/issues/3#issuecomment-453247448_

tomaskovacik, 2019-01-10:
hello, I just did not have time to assemble more units. Currently one is working in my concert1 radio

tomaskovacik, 2019-01-15:
fixed!  its on tindie! :)

Closed 2019-01-15.

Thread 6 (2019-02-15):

implement reset stm32 if front panel is reseted by main mcu

tomaskovacik, 2019-02-15:
HW is ready for this
implement reset of stm32 if reset goes low, or enter sleep or somthing ... or just try wire it directly ...

tomaskovacik, 2021-11-06:
HW reset is doing this, reset circuit was removed (MX809 or R+C) and fastboot bootloader is required

Closed 2019-03-22.

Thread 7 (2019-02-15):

front panel text

tomaskovacik, 2019-02-15:
investigat if fron panel text can be hijacked without spliting HW path between main mcu and front panel,

write documentation with  logic

tomaskovacik, 2019-02-15:
hat I remember:

comunication is bidirectional:
clock is driven  by main MCU always, this is probably mandatory and cant be overwriten
data/clk/status are always HIGH in idle

if slave or master wanna send data they put CLK low, then goes STATUS low and main MCU send/receive data be clk pulses

from memory again, if front panel is sending data I think it STATUS goes LOW, then CLK
if main mcu sending data it was CLK goes LOW then STATUS goes LOW

so important part is
CLK and STATUS must be LOW, then when STATUS goes UP, main MCU will clocking data, as we are 3th person here, and er put CLK and STATUS LOW, no PANEL or MAIN mcu will send data, what will happen is that main MCU will sent 8 clock pulses and will probably read on data line thinking PANEL is sending data, PANEL will also read data line thinking main MCU is sending it. But we will be sending.

so this in theory should be fine, only thing that that can goes wrong is, that only data that PANEL is sendig are button codes and they are always 0x25 then BUTTON_CODE in hex. so if 1st byte wil not be 0x25 main MCU can think that fron panel is drunk and initialize his reset ....

....

tomaskovacik, 2019-02-18:
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

tomaskovacik, 2019-04-07:
1sts tests show that main mcu will initialize restart of whole system if we try to hijack some data on bus

so only posible way is to implement HW split and implement man in the midle

tomaskovacik, 2020-04-11:
this could work:

https://arduino.stackexchange.com/questions/66076/read-write-with-half-duplex-spi

tomaskovacik, 2020-04-28:
resistor which are required to be desoldered:
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
R804 is between main MCU and panel, on top side of PCB:
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

R805 an R806 at bootom side of PCB:
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

communication is bidirectional only on DATA line, CLK and STATUS Are driven by main MCU, so almost standard SPI, 2diodes on STATUS and CLK lines prove it:

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

tomaskovacik, 2020-04-28:
HW3 implementation:

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

I hope HW SPI can be used :)

tomaskovacik, 2020-05-07:
looks like, the front panel is master here:
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

tomaskovacik, 2020-05-07:
standard start:
clk goes high 1st then data and status

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

after ~500ms status goes down :
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

tomaskovacik, 2020-05-08:
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

tomaskovacik, 2024-06-29:
1. switch to HW SPI for reading
2. implement bidirectional SPI

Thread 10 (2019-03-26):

GALA is not supported! DAMN!

tomaskovacik, 2019-03-26:
pin 24 of moto MCU
probably pulses, need to be tested in car ...

https://translate.google.com/translate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

tomaskovacik, 2020-03-13:
gala is square wave duty 50%
 based on testings:

GALA=1

for GALA set to 1 (start radio with TP button switched)
going from ~20Hz up I get these changes in volume/loudness

| freq(Hz) | volume | loudness |
|-------------|-----------|--------------|
|up|
|start|4E|B|
| 105 | 4C,4A | |
| 135 |  | A |
| 167 | 48,46 |  |
| 196 |  | 9 |
| 217 | 44,42 |  |
| 250 |  | 8 |
| 286 | 40,3E |  |
| 308 |  | 7 |
|down|
|286||8|
|256|42||
|220||9|
|197|46||
|178||A|
|149|4A||
|119||B|
|93|4E||

**GALA=2**

| freq(Hz) | volume | loudness |
|-------------|-----------|--------------|
|up|
|start|4E|B|
|85|4C,4A|
|114||A|
|143|48,46|
|169||9|
|206|44,42|
|232||8|
|263|40,3E|
|312||7|
|down|
|256||8|
|222|42|
|204||9|
|178|46|
|154||A|
|126|4A|
|98||B|
|71|4E|

**GALA=3**

| freq(Hz) | volume | loudness |
|-------------|-----------|--------------|
|up|
|start|4E|B|
|68|4C,4A|
|96||A|
|126|48,46|
|154||9|
|189|44,42|
|217||8|
|244|40,3E|
|278||7|
|down|
|238||8|
|217|42|
|185||9|
|164|46|
|137||A|
|110|4A|
|82||B|
|55|4E|

**GALA=4**

| freq(Hz) | volume | loudness |
|-------------|-----------|--------------|
|up|
|start|4A|B|
|78||A|
|107|48,46|
|137||9|
|169|44,42|
|196||8|
|222|40,3E|
|down|
|192|42|
|174||9|
|149|46|
|116||A|
|92|4A|
|65||B|

**GALA=5**

| freq(Hz) | volume | loudness |
|-------------|-----------|--------------|
|up|
|start|52|C|
|39|50,4E|
|68||B|
|92|4C,4A|
|126||A|
|156|48,46|
|189||9|
|222|44,42|
|250||8|
|down|
|213||9|
|185|46|
|161||A|
|137|4A|
|110||B|
|82|4E|
|54||C|

tomaskovacik, 2020-03-14:
velocity goes up: |   |   |   |   |   |   |   |   |  
-- | -- | -- | -- | -- | -- | -- | -- | -- | --
gala | V=4A | L=A | V=46 | L=9 | V=42 | L=8 | V=3E | L=7 |  
1 | 105 | 135 | 167 | 196 | 217 | 250 | 286 | 308 |  
2 | 85 | 114 | 143 | 169 | 206 | 232 | 263 | 312 |  
3 | 68 | 96 | 126 | 154 | 189 | 217 | 244 | 278 |  
4 |   | 78 | 107 | 137 | 169 | 196 | 222 |   |  
5 | 39 | 68 | 92 | 126 | 156 | 189 | 222 | 250 |  
  |   |   |   |   |   |   |   |   |  
velocity goes down: |   |   |   |   |   |   |   |   |  
gala | L=8 | V=42 | L=9 | V=46 | L=A | V=4A | L=B | V=4E | L=C
1 | 286 | 256 | 220 | 197 | 178 | 149 | 119 | 93 |  
2 | 256 | 222 | 204 | 178 | 154 | 126 | 98 | 71 |  
3 | 238 | 217 | 185 | 164 | 137 | 110 | 82 | 55 |  
4 |   | 192 | 174 | 149 | 116 | 92 | 65 |   |  
5 |   |   | 213 | 185 | 161 | 137 | 110 | 82 | 54

this will be implemented, increment of 30km/h up and down gala setting will affect starting speed

gala | V=4A | L=A | V=46 | L=9 | V=42 | L=8 | V=3E | L=7 |  
1 | 100 | 130 | 160 | 190 | 220 | 250 | 280 | 310 |  
2 | 80 | 110 | 140 | 170 | 200 | 230 | 260 | 290 |  
3 | 70 | 100 | 130 | 160 | 190 | 220 | 250 | 280 |  
4 | 50 | 80 | 110 | 140 | 170 | 200 | 230 | 260 |  
5 | 40 | 70 | 100 | 130 | 160 | 190 | 220 | 250 |  
  |   |   |   |   |   |   |   |   |  
velocity goes down: |   |   |   |   |   |   |   |   |  
gala | L=8 | V=42 | L=9 | V=46 | L=A | V=4A | L=B | V=4E | L=C
1 | 280 | 250 | 220 | 190 | 160 | 130 | 100 | 70 | 40
2 | 260 | 230 | 200 | 170 | 140 | 110 | 80 | 50 | 20
3 | 250 | 220 | 190 | 160 | 130 | 100 | 70 | 40 | 10
4 | 230 | 200 | 170 | 140 | 110 | 80 | 50 | 20 | -10
5 |   |   | 220 | 190 | 160 | 130 | 100 | 70 | 40

the default setting will be:
start volume = 3 (4E)
gala=3 (starting speed 70km/h)

this could be changed by starting radio in config mode (pressed and held TP button while powering on the radio), then cycling over the config using TP button, SW will automatically set start volume and gala value based on what will be displayed)

tomaskovacik, 2020-03-16:
start speed calculation:
12-(0xF*GALA):

GALA | START
-- | --
1 | 104
2 | 88
3 | 72
4 | 56
5 | 40

GALA | 1 |   |   |   |   |   |   |   |  
-- | -- | -- | -- | -- | -- | -- | -- | -- | --
  | speed | volume | loudnes |   |   |   |   |   |  
start | 104 | 78 | 11 |   |   |   |   |   |  
HEX: |   | 4E | B |   |   |   |   |   |  
  |   |   |   |   |   |   |   |   |  
ID | 0 | 1 | 2 | 3 | 4 | 5 | 6 | 7 | 8
speed | 104 | 134 | 164 | 194 | 224 | 254 | 284 | 314 | 344
V | -4 | 0 | -4 | 0 | -4 | 0 | -4 | 0 | -4
L | 0 | -1 | 0 | -1 | 0 | -1 | 0 | -1 | 0
  |   |   |   |   |   |   |   |   |  
[V] | 74 | 74 | 70 | 70 | 66 | 66 | 62 | 62 | 58
[L] | 11 | 10 | 10 | 9 | 9 | 8 | 8 | 7 | 7
  |   |   |   |   |   |   |   |   |  
[V(hex)] | 4A | 4A | 46 | 46 | 42 | 42 | 3E | 3E | 3A
[L (hex)] | B | A | A | 9 | 9 | 8 | 8 | 7 | 7

tomaskovacik, 2020-03-20:
speed emulation is made using atmega328 and this Arduino code, it is basic square wave emulator. Frequency can be changed over the serial port.

https://github.com/tomaskovacik/arduino/tree/master/wavegen

tomaskovacik, 2020-03-30:
config menu is sent to display as standard TEXT:

        //TEXT: VOL  1->...->5
        //TEXT: SENS LO
        //TEXT: RM   ON
        //TEXT: NAV  1->...->5
        //TEXT: TEL  L
        //TEXT: TA   1->...->5
        //TEXT: GALA OFF->1-...->5

tomaskovacik, 2020-04-05:
measuring width of pulse on stm32 works on pin PA0 like this:
```
#define GALA PA0
volatile uint16_t captime; // timer count of low pulse (temp)

void TIMER2_ISR()
{
  if ( Timer2.getInputCaptureFlag(TIMER_CH2) && !captime ) // period end
  {
    captime = Timer2.getCompare(TIMER_CH2);//ICR1; // save a copy of current TMR1 count

   }
 }

void setup(){
pinMode(GALA,INPUT_PULLUP);
 Timer2.pause(); // pause timer 2
 //timer2 for GALA:
 Timer2.setPrescaleFactor(72); // 1 microsecond resolution
 // setup timer 2 channel 1 capture on rising edge
 Timer2.setInputCaptureMode(TIMER_CH1, TIMER_IC_INPUT_DEFAULT); // use default input TI1
 // setup timer 2 channel 2 capture on falling edge
 Timer2.setInputCaptureMode(TIMER_CH2, TIMER_IC_INPUT_SWITCH); // use switched input TI1
 Timer2.setPolarity(TIMER_CH2, 1); // trigger on falling edge
 // counter setup as slave triggered by TI1 in reset mode
 Timer2.setSlaveFlags( TIMER_SMCR_TS_TI1FP1 | TIMER_SMCR_SMS_RESET );
 Timer2.refresh();
 Timer2.getCompare(TIMER_CH1); // clear capture flag
 Timer2.getCompare(TIMER_CH2); // clear capture flag
 Timer2.attachInterrupt(TIMER_CH2, TIMER2_ISR); //ch1 is rising edge, it's after low pulse, which we need to process while high pulse ocure...
  Timer2.resume(); // let timer 2 run
}

void loop(){
 if (!captime) {
   Serial.print("Speed=");
   Serial.print((float)1000000 / (2 * captime));
   Serial.println("km/h");
   captime = 0;
 }
}
```

but this will not work for V1, so I change it to standard interrupt:

```
//use PA14 for V1 board
#define GALA PA14 //SWDCLK pin, exposed on version one boards
//PA0 for V2
//#define GALA PA0
volatile uint16_t captime; // timer count of low pulse (temp)

void gala_up(void) {
    Timer2.resume(); // let timer 2 run
    //detachInterrupt(digitalPinToInterrupt(GALA));
    attachInterrupt(digitalPinToInterrupt(GALA), gala_down, FALLING); //
}

void gala_down(void) {
  Timer2.pause();
  //detachInterrupt(digitalPinToInterrupt(GALA));
  captime = Timer2.getCount();
}

void setup(){
pinMode(GALA, INPUT_PULLUP);
  Timer2.setPrescaleFactor(72); // 1 microsecond resolution
  Timer2.refresh();
  Timer2.setCount(0);
  attachInterrupt(digitalPinToInterrupt(GALA), gala_up, RISING);
}

void setup(){
  if (captime>0) {
    Serial.print("Speed=");
    Serial.print((float)1000000 / (2 * captime));
    Serial.println("km/h");
    Timer2.setCount(0);
    captime=0;
    attachInterrupt(digitalPinToInterrupt(GALA), gala_up, RISING); //
  }
}
```

tomaskovacik, 2020-04-10:
hopefully 4e7bda1ff9f302e4176b3303eb5a1d47f9de1e90 fix this, but it need to be tested in car!

for version 1.0 of HW, 1k resistor need to be put between CLK pin of ST-LINK connector and gala signal, on resistor R2304 :+1:

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

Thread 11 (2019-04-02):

full volume

tomaskovacik, 2019-04-02:
reported by email:

Run it twice to confirm. Obviously not using devel version for this...

Change sound settings to 0 (fad, bal, treb, bass) just to be sure this doesn't interfere.
Put on some radio station. Volume around 30% so you don't want to turn it off earlier :D
Leave it on. Radio will turn off itself after 1 hour.

Then you press in center button to really turn it physically off. Then again turn it on.
Notice current volume (should be quieter than previous).
Check sound settings but don't change them. Should be the same 0.

Wait for settings to exit back to radio station. Try increasing sound volume to MAX. Will not be possible.

fixed in

Open sound settings. Change any of them by +1 position. Sound will jump to real MAX.

tomaskovacik, 2019-04-02:
can't reproduce on chorus, try one more time ..

tomaskovacik, 2019-04-03:
cannot reproduce :/ if anyone experience this, please reopen

Closed 2019-04-03.

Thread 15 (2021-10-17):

high currnet consumption when radio is OFF

tomaskovacik, 2021-10-17:
measure standby current,

- is the resetting circuit working ?
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

- if not implement low power https://github.com/stm32duino/STM32LowPower this will require port to stm32core instead of roger Clarks core ...

tomaskovacik, 2021-10-17:
try without MAX809 reset IC and with direct connection of RESET_KA to RESET ->> possibility of SW problems, whole setup will be fired not just main loop! But again, this is 72MHz beast, main mcu in radio is "just" 4MHZ

tomaskovacik, 2021-10-17:
e87dfa52bfaec7143e7a4c8bd6e8c002198cefaf has easy hot fix to make it require only 24mA
5mA is possible if reset circuit is  deleted, and RESET_KA  is connected via 1k resistor (some modules do not have it connected. But whole setup did not work in this scenario, close main Motorola mcu sends some data before it actually wake up front panel, so this module is late for catching data on i2c line :(

tomaskovacik, 2021-11-06:
e87dfa5 is not required anymore, it was reverted, a lot of delays in code were removed in b188e217825734cb50a7dfdaa8711675cc589180

Closed 2021-11-06.

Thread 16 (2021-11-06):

try setup without USB bootloader

tomaskovacik, 2021-11-06:
using STlink upload or serial bootloader

serial bootloader upload will not be possible for V1 boards

tomaskovacik, 2021-11-12:
fixed fa95c79bc9c4cb7128a013416e649e84ca4194b4

Closed 2021-11-12.

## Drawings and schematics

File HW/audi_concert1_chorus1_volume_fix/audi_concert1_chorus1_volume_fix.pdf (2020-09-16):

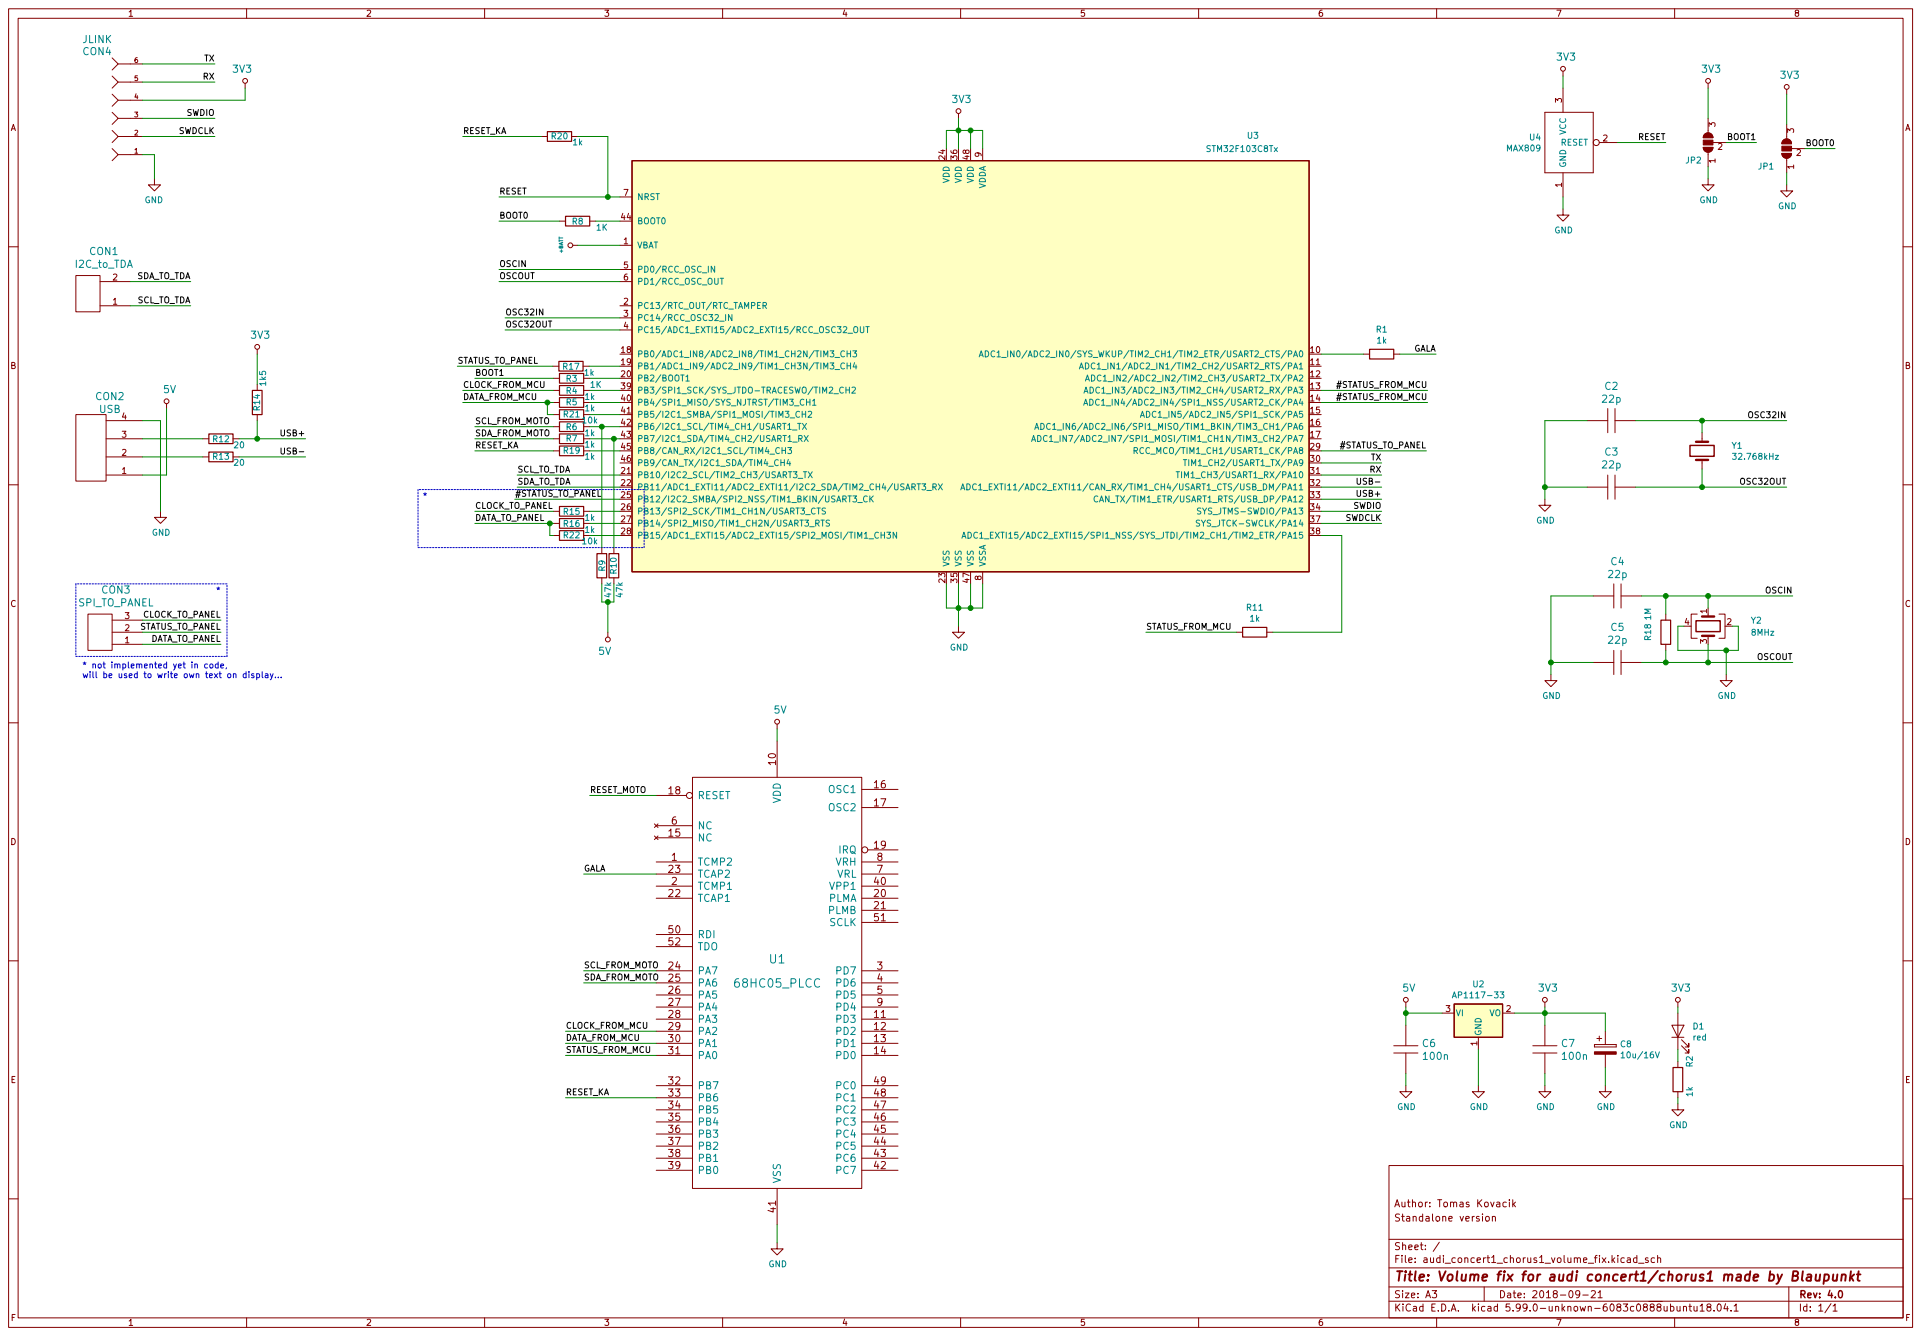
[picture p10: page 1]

3 CON3
will be used to write own text on display... *

* not implemented yet in code,

Id: 1/1 Title: Volume fix for audi concert1/chorus1 made by Blaupunkt

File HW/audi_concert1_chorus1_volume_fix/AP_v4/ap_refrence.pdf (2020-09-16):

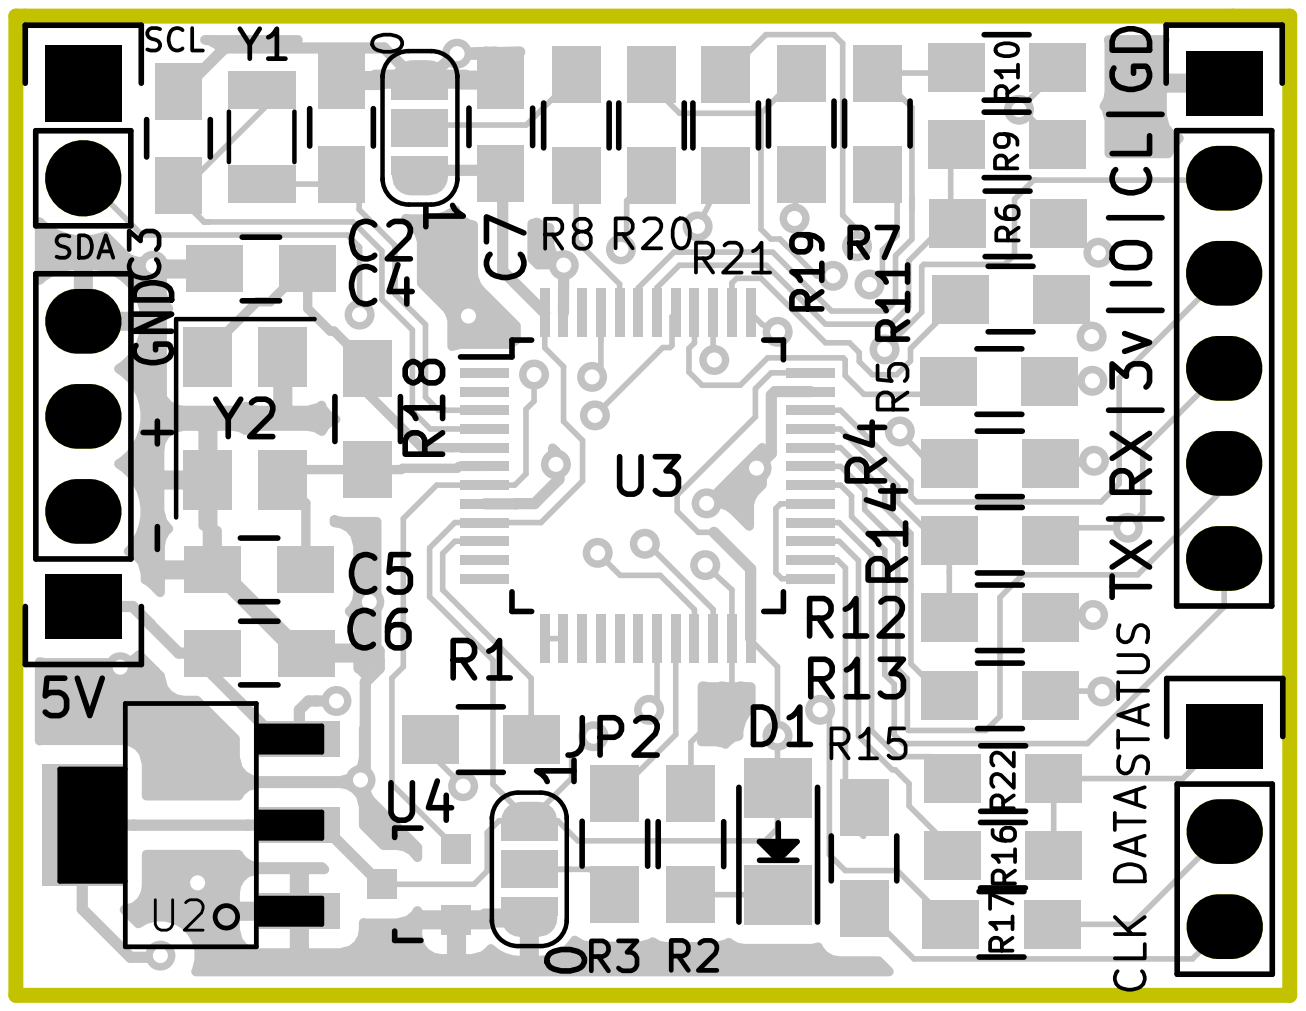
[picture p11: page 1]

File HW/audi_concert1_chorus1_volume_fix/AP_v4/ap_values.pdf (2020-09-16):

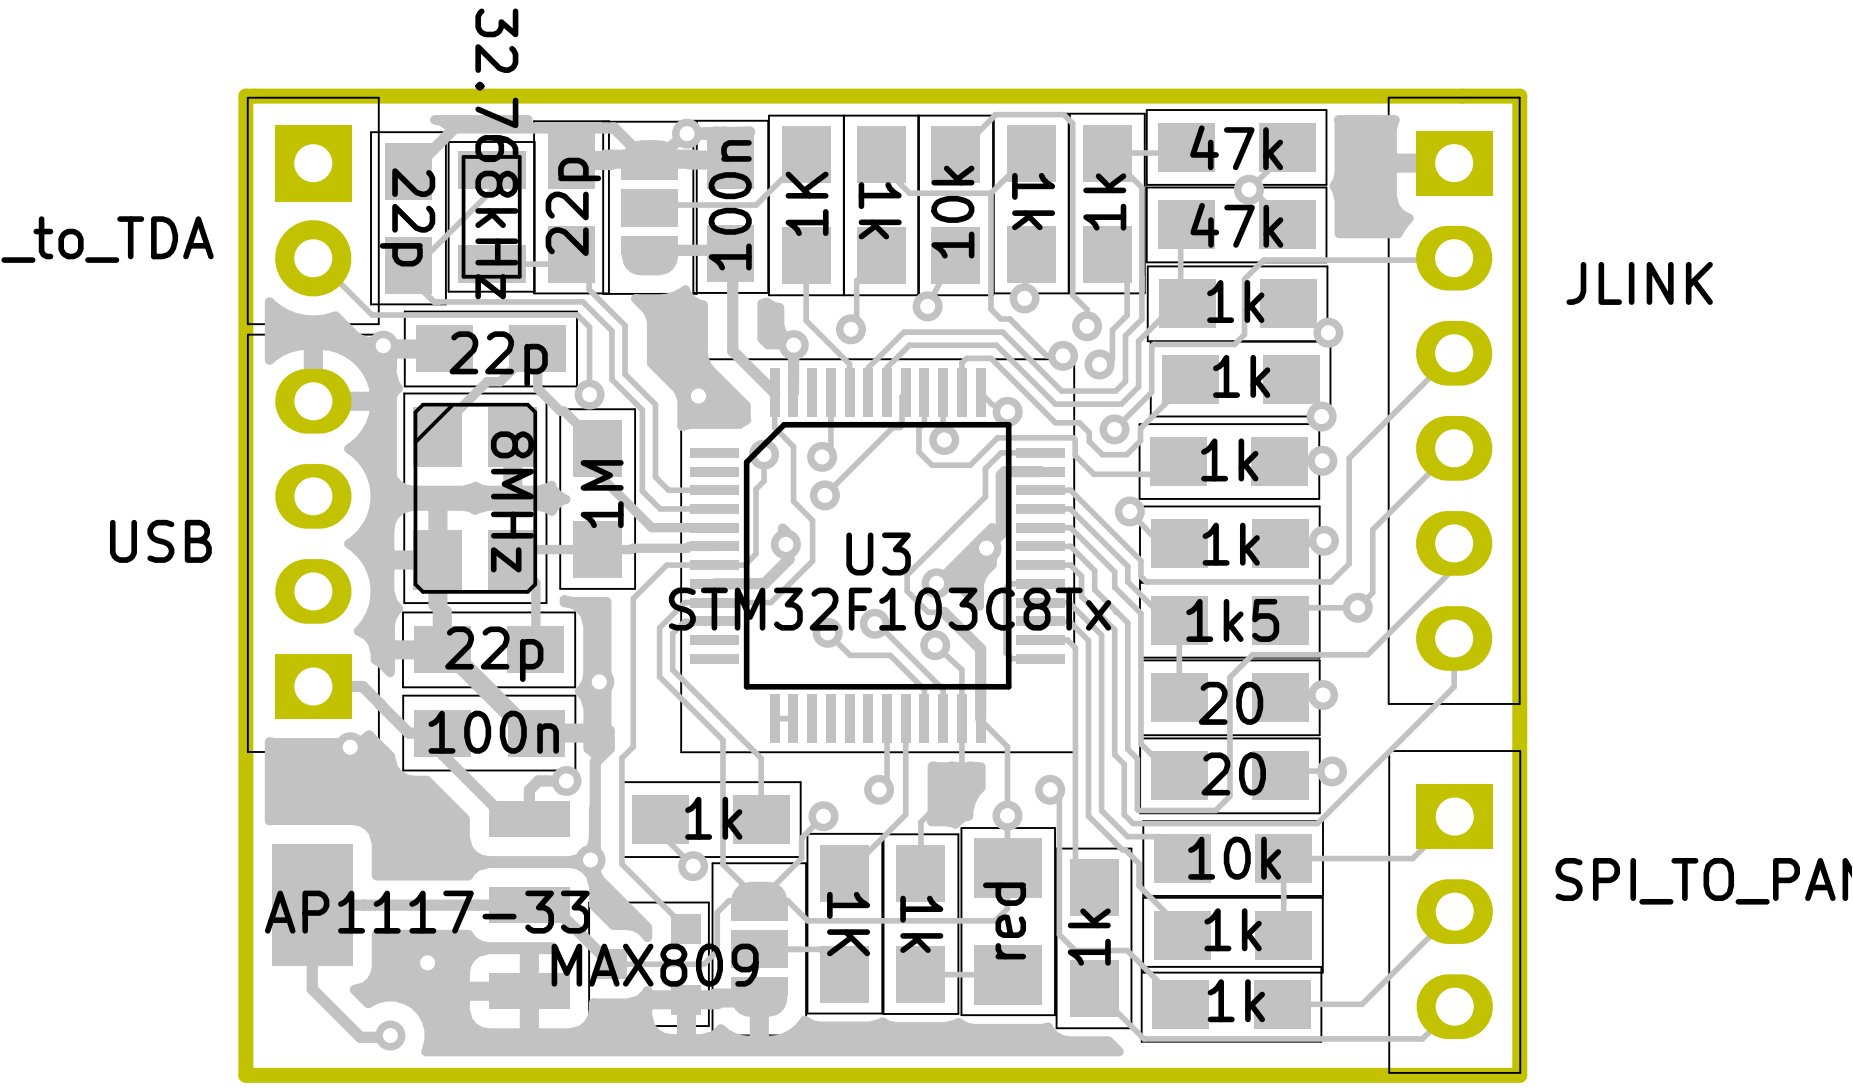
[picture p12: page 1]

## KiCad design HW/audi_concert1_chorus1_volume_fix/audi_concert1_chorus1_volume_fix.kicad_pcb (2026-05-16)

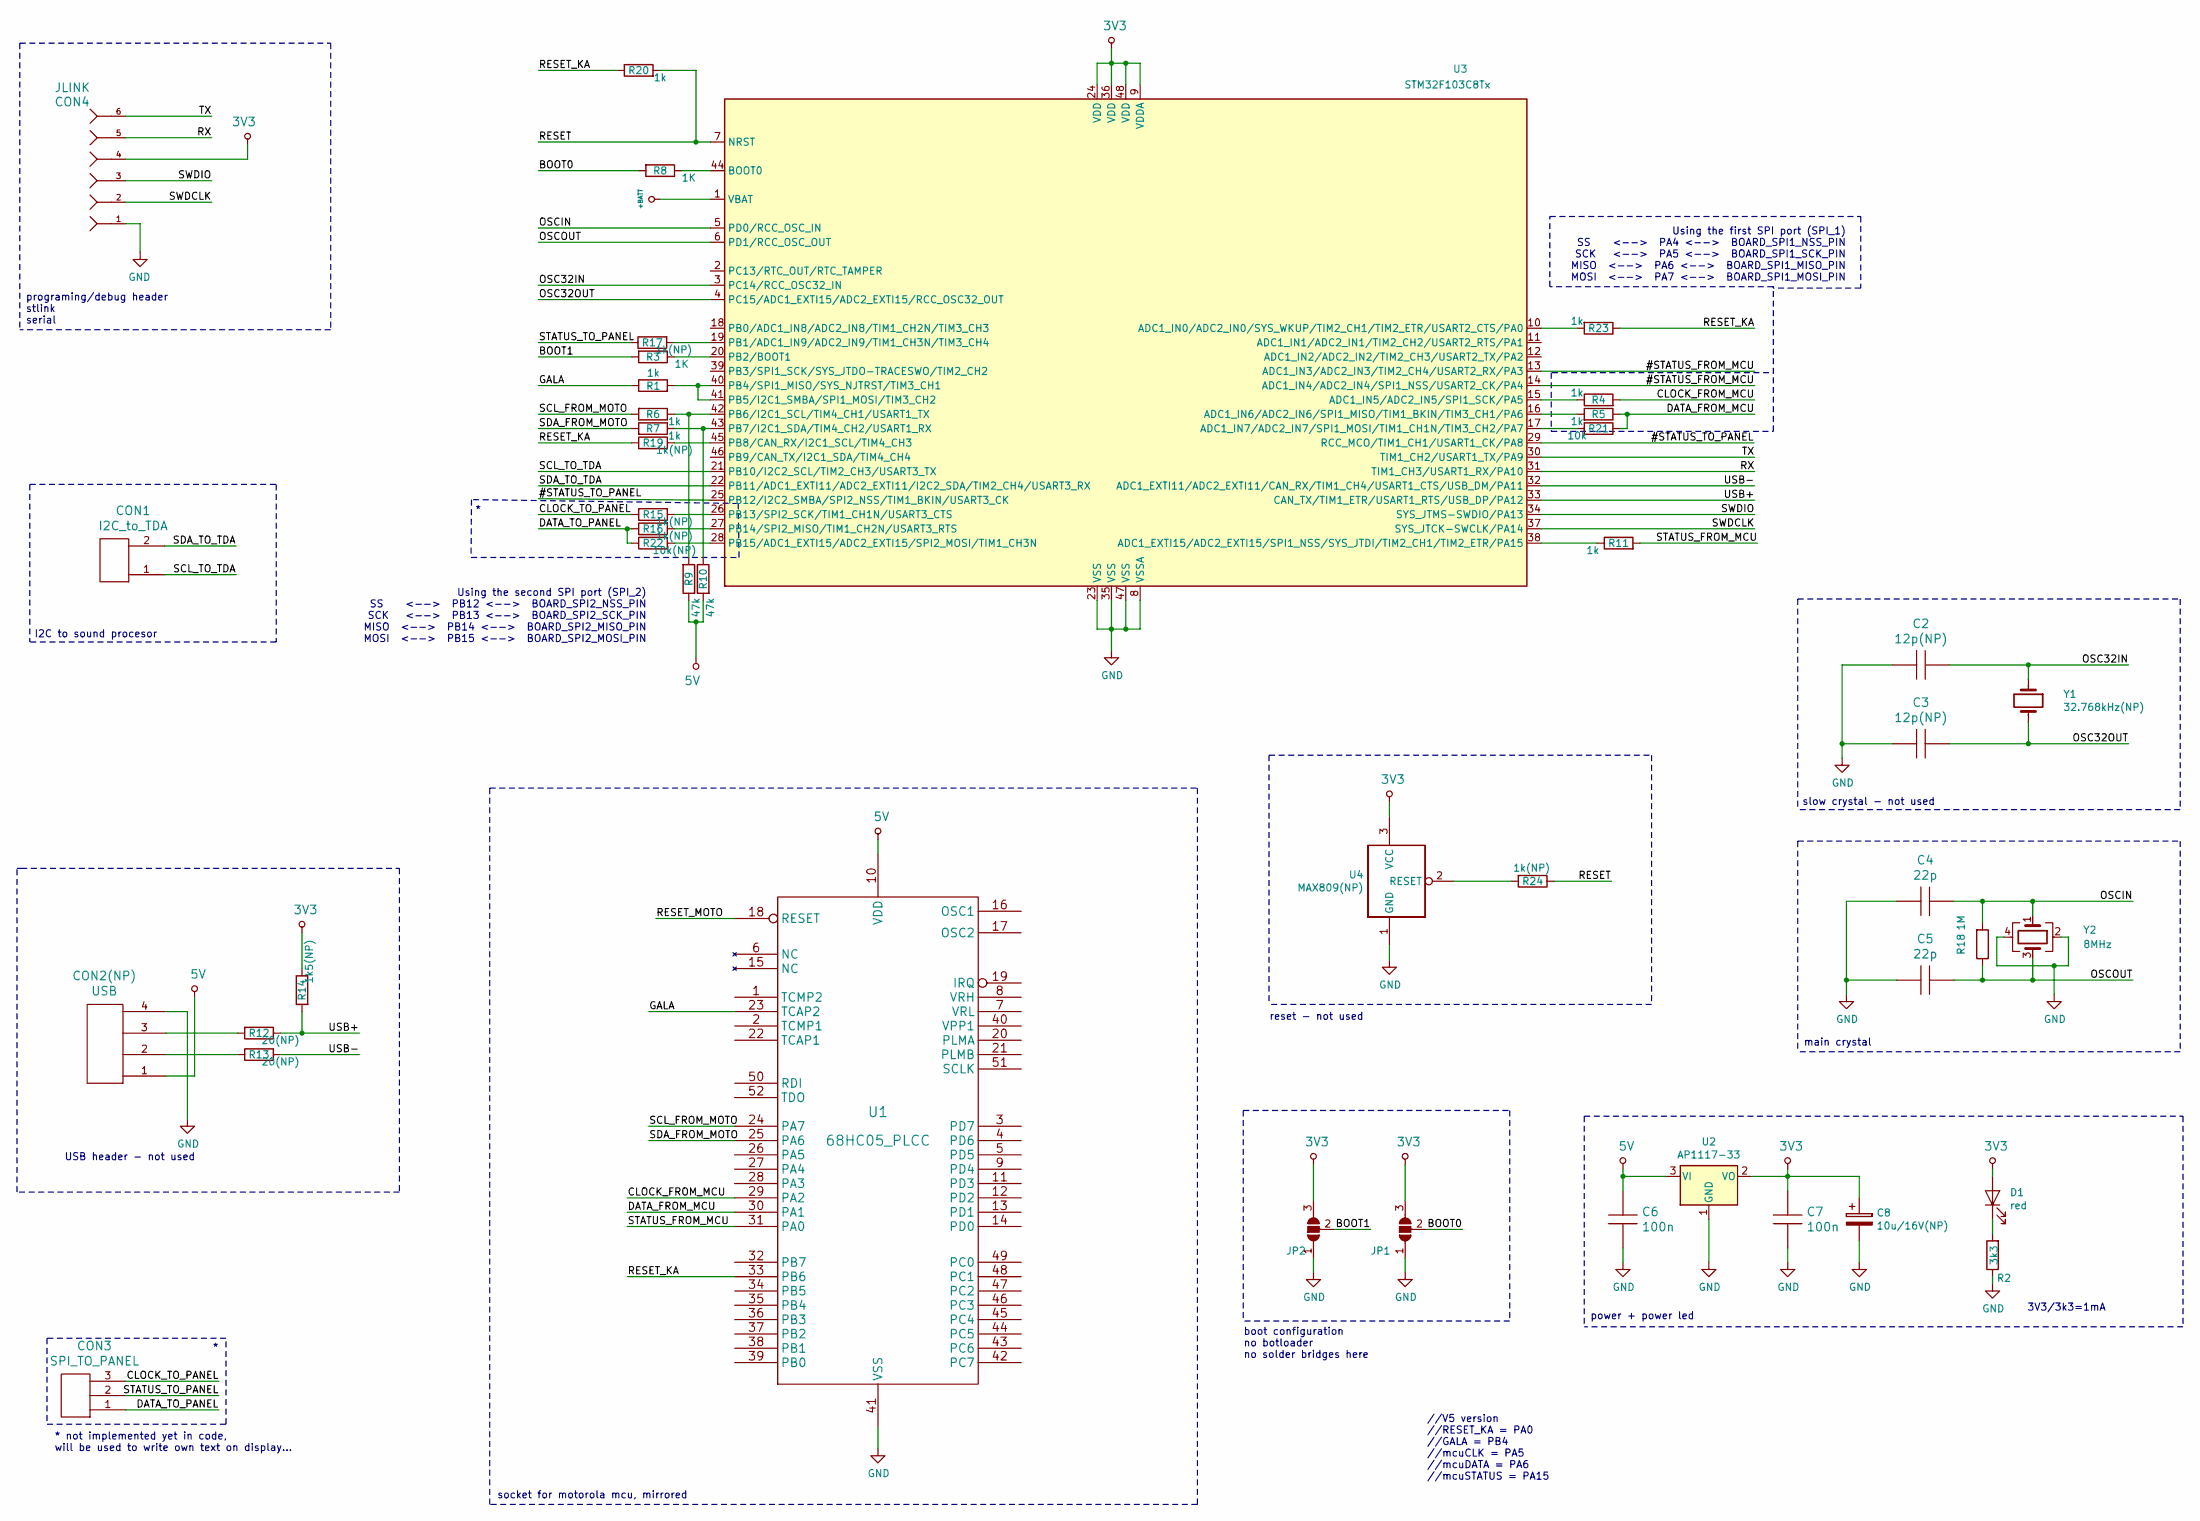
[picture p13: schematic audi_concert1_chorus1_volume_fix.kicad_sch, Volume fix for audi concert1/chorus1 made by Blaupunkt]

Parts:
C2, C3: 12p(NP); C_0805_HandSoldering
C4, C5: 22p; C_0805_HandSoldering
C6, C7: 100n; C_0805_HandSoldering
C8: 10u/16V(NP); TantalC_SizeA_EIA-3216_HandSoldering
CON1: I2C_to_TDA; Pin_Header_Straight_1x02
CON2(NP): USB; Pin_Header_Straight_1x04
CON3: SPI_TO_PANEL; Pin_Header_Straight_1x03
CON4: JLINK; Pin_Header_Straight_1x06
D1: red; LED-1206
JP1, JP2: SolderJumper_3_Open; SolderJumper-3_P1.3mm_Open_RoundedPad1.0x1.5mm_NumberLabels
R1, R4, R5, R6, R7, R11, R20, R23: 1k; R_0805_HandSoldering
R2: 3k3; R_0805_HandSoldering
R3, R8: 1K; R_0805_HandSoldering
R9, R10: 47k; R_0805_HandSoldering
R12, R13: 20(NP); R_0805_HandSoldering
R14: 1k5(NP); R_0805_HandSoldering
R15, R16, R17, R19, R24: 1k(NP); R_0805_HandSoldering
R18: 1M; R_0805_HandSoldering
R21: 10k; R_0805_HandSoldering
R22: 10k(NP); R_0805_HandSoldering
U1: 68HC05_PLCC; PLCC-52_mirrored
U2: AP1117-33; AB2_SOT223
U3: STM32F103C8Tx; LQFP-48_7x7mm_Pitch0.5mm
U4: MAX809(NP); SOT-23
Y1: 32.768kHz(NP); Crystal_SMD_3215-2pin_3.2x1.5mm
Y2: 8MHz; Crystal_SMD_5032-4pin_5.0x3.2mm

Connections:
3V3: C7.1, C8.1, CON4.4, D1.2 (A), JP1.3 (B), JP2.3 (B), R14.1, U2.2 (VO), U3.9 (VDDA), U3.24 (VDD), U3.36 (VDD), U3.48 (VDD), U4.3 (VCC)
5V: C6.1, CON2(NP).1, R9.1, R10.2, U1.10 (VDD), U2.3 (VI); also elsewhere on the board
+BATT: U3.1 (VBAT)
/#STATUS_FROM_MCU: U3.13 (ADC1_IN3/ADC2_IN3/TIM2_CH4/USART2_RX/PA3), U3.14 (ADC1_IN4/ADC2_IN4/SPI1_NSS/USART2_CK/PA4)
/#STATUS_TO_PANEL: U3.25 (PB12/I2C2_SMBA/SPI2_NSS/TIM1_BKIN/USART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), U3.29 (RCC_MCO/TIM1_CH1/USART1_CK/PA8)
/BOOT0: JP1.2 (C), R8.2
/BOOT1: JP2.2 (C), R3.2
/CLOCK_FROM_MCU: R4.2, U1.29 (PA2)
/CLOCK_TO_PANEL: CON3.3, R15.1
/DATA_FROM_MCU: R5.1, R21.1, U1.30 (PA1)
/DATA_TO_PANEL: CON3.1, R16.1, R22.1
/GALA: R1.1, U1.23 (TCAP2)
/OSC32IN: C2.1, U3.3 (PC14/RCC_OSC32_IN), Y1.1
/OSC32OUT: C3.2, U3.4 (PC15/ADC1_EXTI15/ADC2_EXTI15/RCC_OSC32_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), Y1.2
/OSCIN: C4.1, R18.2, U3.5 (PD0/RCC_OSC_IN), Y2.1
/OSCOUT: C5.2, R18.1, U3.6 (PD1/RCC_OSC_OUT), Y2.3
/RESET: R20.2, R24.1, U3.7 (NRST)
/RESET_KA: R19.1, R20.1, R23.1, U1.33 (PB6)
/RESET_MOTO: U1.18 (RESET)
/RX: CON4.5, U3.31 (TIM1_CH3/USART1_RX/PA10)
/SCL_FROM_MOTO: R6.2, U1.24 (PA7)
/SCL_TO_TDA: CON1.1, U3.21 (PB10/I2C2_SCL/TIM2_CH3/USART3_TX)
/SDA_FROM_MOTO: R7.2, U1.25 (PA6)
/SDA_TO_TDA: CON1.2, U3.22 (PB11/ADC1_EXTI11/ADC2_EXTI11/I2C2_SDA/T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)
/STATUS_FROM_MCU: R11.2, U1.31 (PA0)
/STATUS_TO_PANEL: CON3.2, R17.1
/SWDCLK: CON4.2, U3.37 (SYS_JTCK-SWCLK/PA14)
/SWDIO: CON4.3, U3.34 (SYS_JTMS-SWDIO/PA13)
/TX: CON4.6, U3.30 (TIM1_CH2/USART1_TX/PA9)
/USB+: R12.1, R14.2, U3.33 (CAN_TX/TIM1_ETR/USART1_RTS/USB_DP/PA12)
/USB-: R13.2, U3.32 (ADC1_EXTI11/ADC2_EXTI11/CAN_RX/TIM1_CH4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)
GND: C2.2, C3.1, C4.2, C5.1, C6.2, C7.2, C8.2, CON2(NP).4, CON4.1, JP1.1 (A), JP2.1 (A), R2.1, U1.41 (VSS), U2.1 (GND), U3.8 (VSSA), U3.23 (VSS), U3.35 (VSS), U3.47 (VSS), U4.1 (GND), Y2.2, Y2.4; also elsewhere on the board
unnamed 32: CON2(NP).2, R13.1; also elsewhere on the board
unnamed 33: CON2(NP).3, R12.2; also elsewhere on the board
unnamed: D1.1 (K), R2.2
unnamed: R1.2, U3.40 (PB4/SPI1_MISO/SYS_NJTRST/TIM3_CH1), U3.41 (PB5/I2C1_SMBA/SPI1_MOSI/TIM3_CH2)
unnamed: R3.1, U3.20 (PB2/BOOT1)
unnamed: R4.1, U3.15 (ADC1_IN5/ADC2_IN5/SPI1_SCK/PA5)
unnamed: R5.2, U3.16 (ADC1_IN6/ADC2_IN6/SPI1_MISO/TIM1_BKIN/T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)
unnamed: R6.1, R9.2, U3.42 (PB6/I2C1_SCL/TIM4_CH1/USART1_TX)
unnamed: R8.1, U3.44 (BOOT0)
unnamed: R7.1, R10.1, U3.43 (PB7/I2C1_SDA/TIM4_CH2/USART1_RX)
unnamed: R11.1, U3.38 (ADC1_EXTI15/ADC2_EXTI15/SPI1_NSS/SYS_JT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)
unnamed: R15.2, U3.26 (PB13/SPI2_SCK/TIM1_CH1N/USART3_CTS)
unnamed: R16.2, U3.27 (PB14/SPI2_MISO/TIM1_CH2N/USART3_RTS)
unnamed: R17.2, U3.19 (PB1/ADC1_IN9/ADC2_IN9/TIM1_CH3N/TIM3_CH4)
unnamed: R19.2, U3.45 (PB8/CAN_RX/I2C1_SCL/TIM4_CH3)
unnamed: R21.2, U3.17 (ADC1_IN7/ADC2_IN7/SPI1_MOSI/TIM1_CH1N/T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)
unnamed: R22.2, U3.28 (PB15/ADC1_EXTI15/ADC2_EXTI15/SPI2_MOSI/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)
unnamed: R23.2, U3.10 (ADC1_IN0/ADC2_IN0/SYS_WKUP/TIM2_CH1/TIM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)
unnamed: R24.2, U4.2 (RESET)

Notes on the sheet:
boot configuration no botloader no solder bridges here
Using the second SPI port (SPI_2) SS <--> PB12 <--> BOARD_SPI2_NSS_PIN SCK <--> PB13 <--> BOARD_SPI2_SCK_PIN MISO <--> PB14 <--> BOARD_SPI2_MISO_PIN MOSI <--> PB15 <--> BOARD_SPI2_MOSI_PIN
power + power led
* not implemented yet in code, will be used to write own text on display...
socket for motorola mcu, mirrored
USB header - not used
Using the first SPI port (SPI_1) SS <--> PA4 <--> BOARD_SPI1_NSS_PIN SCK <--> PA5 <--> BOARD_SPI1_SCK_PIN MISO <--> PA6 <--> BOARD_SPI1_MISO_PIN MOSI <--> PA7 <--> BOARD_SPI1_MOSI_PIN
I2C to sound procesor
3V3/3k3=1mA
slow crystal - not used
//V5 version //RESET_KA = PA0 //GALA = PB4 //mcuCLK = PA5 //mcuDATA = PA6 //mcuSTATUS = PA15
reset - not used
main crystal
programing/debug header stlink serial

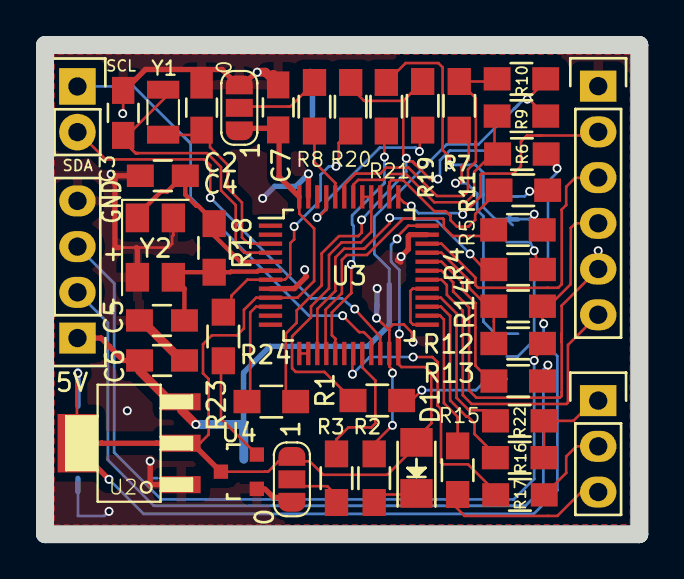
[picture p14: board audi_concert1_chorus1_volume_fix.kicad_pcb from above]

Board: 2 copper layers, 33.0 x 27.2 mm, 44 parts (1 on the bottom side), 49 nets.

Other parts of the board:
CON2: USB; Pin_Header_Straight_1x04

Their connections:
5V: CON2.1; also elsewhere on the board
GND: CON2.4; also elsewhere on the board
unnamed 32: CON2.2; also elsewhere on the board
unnamed 33: CON2.3; also elsewhere on the board

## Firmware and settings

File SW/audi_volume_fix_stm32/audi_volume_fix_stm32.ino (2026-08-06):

// HWv5 — dual-SPI man-in-the-middle bridge for Audi Concert1/Chorus1 volume fix
// STM32 intercepts SPI between radio MCU and front panel, forwarding and modifying packets.
// Define HWV5_BRIDGE to activate bridge mode (active); omit for passive sniff mode.
//
// Bridge pin assignment:
//   MCU side  (SPI1 slave):  PA5=SCK, PA7=MOSI, PA15=STATUS(OUTPUT), PA3=CS
//   Panel side (SPI2 master): PB13=SCK, PB14=MISO, PB15=MOSI, PB1=STATUS(INPUT), PA8=CS
//   GALA: PB5 (TIM3_CH2, speed pulse from HC05 pin23 via 1kΩ — optional)

/* version 5 — bridge mode (replaces passive sniffer with active man-in-the-middle)
mcuCLK    = PA5  (SPI1_SCK  - input, MCU drives CLK)
mcuDATA   = PA7  (SPI1_MOSI - data received by STM32 in slave mode)
mcuSTATUS = PA15 (OUTPUT: STM32 drives STATUS to MCU, acting as front panel)
mcuCS     = PA3  (output: hw-inverted PA15, mirrors SPI1_NSS on board)
panelCLK    = PB13 (SPI2_SCK  output to panel)
panelMOSI   = PB15 (SPI2_MOSI output to panel)
panelMISO   = PB14 (SPI2_MISO input from panel)
panelSTATUS = PB1  (input: panel drives STATUS)
panelCS     = PA8  (output: hw-inverted PB1)
*/
#define HWV5_BRIDGE
#include <SPI.h>
#include <Wire.h>
#include <FlexWire.h>
#include "audi_concert_panel.h"

FlexWire SWire = FlexWire(PB11, PB10);

#ifdef HWV5_BRIDGE
SPIClass SPI_2(PB15, PB14, PB13);  // SPI2: PB13=SCK, PB14=MISO, PB15=MOSI (panel side master)
#endif

#define USE_SERIAL
#define USEDSERIAL Serial1

// ── Config flash storage ───────────────────────────────────────────────────
// STM32F103C6 = 32KB flash. Reserve the last 1KB page for config.
// We only write on explicit serial command so no wear-levelling needed.
#define CFG_FLASH_PAGE  ((uint32_t)(0x08000000u + 32u*1024u - 1u*1024u))  // 0x8007C00
#define CFG_MAGIC0  0xA5u
#define CFG_MAGIC1  0x5Au
#define CFG_MAGIC2  0xC3u


#define DEFAULT_VOL   3
#define DEFAULT_GALA  0   // GALA off by default
#define DEFAULT_TA    3

// GALA speed input pin (PB5 = TIM3_CH2, tied with PB4/TIM3_CH1 — parallel with HC05 pin23, BC558 PNP high-side driver via 1kΩ)
#define GALA_PIN  PB5
/*
    SPI communication between motorola MC68HC05B32 cpu to front panel ST6280
    basics:
    SPI MODE 0

    CLK idle high, while
    STATUS idle high, it's like CS but it's triggered by slave here)
    DATA idle high

    communication principle:
    CLK line going LOW is signaling someone wanna talk
    whatever it's slave (panel, cose we have buttons there ...) or master
    after CLK is low, slave bring STATE line LOW, and when he is ready to
    receive data he will bring STATE HIGH, then master will clock out data
    or clock in data, after everything is transmitted, CLOCK goes HIGH and
    shortly after this STATE goes HIGH signaling end of packet.
    While CLK is still low after STATE goes LOW, signaling there is probably
    more data to come.

*/
#define mcuCLK    PA5  // SPI1_SCK  - MCU drives CLK (input, passive sniff)
#define mcuDATA   PA7  // SPI1_MOSI - shared DATA via resistors (input, passive sniff)
#define mcuCS     PA3  // output: mirrors STATUS → HW inverter → SPI1_NSS (PA4)
#define mcuSTATUS PA15
#ifdef HWV5_BRIDGE
// Panel side (SPI2 master) — STM32 acts as Audi MCU toward front panel
#define panelCLK    PB13  // SPI2_SCK  - output to panel
#define panelMOSI   PB15  // SPI2_MOSI - output to panel (10k resistor in HW)
#define panelMISO   PB14  // SPI2_MISO - input from panel (1k resistor in HW)
#define panelSTATUS PB1   // STATUS from panel (input, panel drives this)
#define panelCS     PA8   // CS to panel: output = !PB1 (hw wired to PB12 for inversion)
#endif
#define displayRESET PB8
#define VERSION "2.1-25.05.26-HWv5"

//we are trying to interface with communication to TDA7342 which is 0x44 so...
#define I2C_7BITADDR 0x44
//array is flat circular buffer of howmanypackets * howmanybytesinpacket bytes
#define howmanypackets 20
#define howmanybytesinpacket 15
#define PACKET_IDX(pkt, byte) ((pkt) * howmanybytesinpacket + (byte))

const byte MY_ADDRESS = I2C_7BITADDR;

/*
   CircularPacketBuffer - wraps a flat byte array as a circular queue of fixed-size
   packets (howmanypackets x howmanybytesinpacket).

   read(dst)  - copy current read packet into dst[] and advance rdp
   write(val) - append val to the current write packet at wbp and advance wbp
   commit()   - zero-fill remaining bytes in write packet then advance wdp
   available()- true when at least one unread packet is waiting
   busy       - set by ISR while actively writing a packet; main loop must not
                read while busy is set
*/
struct CircularPacketBuffer {
  volatile uint8_t *buf;
  volatile uint8_t rdp;  // read packet pointer
  volatile uint8_t wdp;  // write packet pointer
  volatile uint8_t wbp;  // write byte pointer within current write packet
  volatile bool busy;    // ISR-active flag

  bool available() const { return rdp != wdp; }

  // Copy the current read packet into dst[] then advance rdp.
  // No zero-fill needed — commit() zero-fills on write.
  void read(uint8_t dst[]) {
    for (uint8_t i = 0; i < howmanybytesinpacket; i++)
      dst[i] = buf[PACKET_IDX(rdp, i)];
    if (++rdp == howmanypackets) rdp = 0;
  }

  // Append val at wbp in the current write packet and advance wbp
  void write(uint8_t val) {
    buf[PACKET_IDX(wdp, wbp)] = val;
    wbp++;
  }

  // Zero-fill remaining bytes in current write packet then advance wdp
  // Silently drops the packet if the buffer is full (wdp would lap rdp).
  void commit() {
    while (wbp < howmanybytesinpacket) buf[PACKET_IDX(wdp, wbp++)] = 0;
    wbp = 0;
    uint8_t next = wdp + 1;
    if (next == howmanypackets) next = 0;
    if (next != rdp) wdp = next; // drop silently if full
  }
};

/*
   Flat backing arrays for the two circular packet buffers.
   Access them only through the panel_message / i2c_data helper objects below.
*/
volatile uint8_t _panel_msg_buf[howmanypackets * howmanybytesinpacket]; // SPI front-panel data
volatile uint8_t _i2c_data_buf[howmanypackets * howmanybytesinpacket];  // I2C data from MCU

CircularPacketBuffer panel_message = { _panel_msg_buf, 0, 0, 0, false }; // SPI front panel messages
CircularPacketBuffer i2c_data      = { _i2c_data_buf,  0, 0, 0, false }; // I2C packets from MCU

#ifdef HWV5_BRIDGE
// ── Bridge circular buffers (SPI1↔SPI2 man-in-the-middle) ────────────────────────
#define CIRC_BUF_SIZE 256
struct CircBuf {
    volatile uint8_t  data[CIRC_BUF_SIZE];
    volatile uint16_t head = 0, tail = 0;
    void push(uint8_t b) { uint16_t n=(head+1)%CIRC_BUF_SIZE; if(n!=tail){data[head]=b;head=n;} }
    bool pop(uint8_t &b) { if(head==tail)return false; b=data[tail]; tail=(tail+1)%CIRC_BUF_SIZE; return true; }
    bool empty() const { return head==tail; }
    bool full()  const { return ((head+1)%CIRC_BUF_SIZE)==tail; }
};
CircBuf mcu_to_panel;  // SPI1 RX → SPI2 TX  (MCU→panel display data)
CircBuf panel_to_mcu;  // SPI2 RX → SPI1 TX  (panel→MCU button data)

// Direct packet array for MCU→panel data (populated by SPI1 ISR)
volatile uint8_t _msg[howmanypackets][howmanybytesinpacket];
volatile uint8_t dwdp = 0;   // write packet pointer (ISR)
volatile uint8_t dwbp = 0;   // write byte pointer (ISR)
volatile uint8_t drdp = 0;   // read packet pointer (loop)
volatile uint8_t grabbing_SPI = 0;  // set by ISR during active byte capture

// Panel→MCU packet mirror array
volatile uint8_t _panel_msg[howmanypackets][howmanybytesinpacket];
volatile uint8_t panel_dwdp = 0, panel_dwbp = 0, panel_drdp = 0;
volatile uint8_t panel_grabbing_SPI = 0;

// Set by panelStatusChange ISR when panel wants to send button data
volatile uint8_t panel_wants_to_send = 0;
// Set in loop() when we signal MCU that panel has button data via STATUS LOW
volatile uint8_t mcu_read_initiated = 0;
#endif

Config cfg;  // loaded once in setup(), updated on serial command

volatile uint8_t volume         = 0xBA;
volatile uint8_t current_volume = 0xBA;
volatile uint8_t saved_volume   = 0xBA;

volatile uint8_t loudness         = 0x0E;
volatile uint8_t current_loudness = 0x0E;

volatile bool grab_volume    = true;
volatile bool mute           = false;
volatile bool in_volume_recalc = false;

// GALA state
volatile uint16_t gala_captime = 0;  // pulse width in µs (filled by ISR)
uint16_t gala_prev_speed = 0;
// Rolling average over last 8 pulses to suppress ±1 µs jitter
#define GALA_AVG_N 8
static uint16_t gala_pulse_buf[GALA_AVG_N];
static uint8_t  gala_pulse_idx = 0;
static bool     gala_buf_full  = false;

bool displayRESETstate = false;

uint8_t volume_packet[howmanybytesinpacket];
uint8_t loudness_packet[howmanybytesinpacket];


void sendI2C(const uint8_t data[howmanybytesinpacket]);


void set_volume();
void set_loudness();

void set_mute();
void set_unmute();
void receiveEvent(int howMany);
#ifdef HWV5_BRIDGE
void mcuClkChange();
void spi1ByteReceived();
void panelStatusChange();
void receivePanelPacket();
void sendToPanel();
#endif

// ── Config (raw flash, 1KB page) ──────────────────────────────────────────

static Config readConfig() {
  const Config *p = (const Config *)CFG_FLASH_PAGE;
  Config c = *p;
  if (c.magic[0] == CFG_MAGIC0 && c.magic[1] == CFG_MAGIC1 && c.magic[2] == CFG_MAGIC2
      && c.crc == (uint8_t)(c.vol + c.gala + c.ta)) {
    // CRC ok — clamp each field to valid range (guard against partial flash corruption)
    if (c.vol  < 1 || c.vol  > 5) c.vol  = DEFAULT_VOL;
    if (c.gala > 5)                c.gala = DEFAULT_GALA;
    if (c.ta   < 1 || c.ta   > 5) c.ta   = DEFAULT_TA;
    return c;
  }
  // magic/CRC mismatch — full defaults
  c.magic[0] = CFG_MAGIC0; c.magic[1] = CFG_MAGIC1; c.magic[2] = CFG_MAGIC2;
  c.vol  = DEFAULT_VOL;
  c.gala = DEFAULT_GALA;
  c.ta   = DEFAULT_TA;
  c.crc  = c.vol + c.gala + c.ta;
  return c;
}

static bool writeConfig(Config c) {
  c.magic[0] = CFG_MAGIC0; c.magic[1] = CFG_MAGIC1; c.magic[2] = CFG_MAGIC2;
  c.crc = c.vol + c.gala + c.ta;
  HAL_FLASH_Unlock();
  FLASH_EraseInitTypeDef eraseInit;
  eraseInit.TypeErase   = FLASH_TYPEERASE_PAGES;
  eraseInit.PageAddress = CFG_FLASH_PAGE;
  eraseInit.NbPages     = 1;
  uint32_t pageError    = 0;
  HAL_FLASHEx_Erase(&eraseInit, &pageError);
  const uint16_t *src_words = (const uint16_t *)&c;
  uint32_t flash_addr = CFG_FLASH_PAGE;
  for (uint8_t i = 0; i < (sizeof(Config) + 1) / 2; i++, flash_addr += 2)
    if (HAL_FLASH_Program(FLASH_TYPEPROGRAM_HALFWORD, flash_addr, (uint64_t)src_words[i]) != HAL_OK) {
      HAL_FLASH_Lock();
#ifdef USE_SERIAL
      USEDSERIAL.print(F("CFG_SAVE: FAIL vol=")); USEDSERIAL.print(c.vol);
      USEDSERIAL.print(F(" gala="));              USEDSERIAL.print(c.gala);
      USEDSERIAL.print(F(" ta="));                USEDSERIAL.println(c.ta);
#endif
      return false;
    }
  HAL_FLASH_Lock();
#ifdef USE_SERIAL
  USEDSERIAL.print(F("CFG_SAVE: OK vol=")); USEDSERIAL.print(c.vol);
  USEDSERIAL.print(F(" gala="));            USEDSERIAL.print(c.gala);
  USEDSERIAL.print(F(" ta="));              USEDSERIAL.println(c.ta);
#endif
  return true;
}

static uint8_t volLevelToHex(uint8_t level) {
  // levels 1-5 → volume hex (higher = quieter on TDA7342)
  static const uint8_t tbl[] = { 0xC2, 0xBE, 0xBA, 0xB6, 0xB2 };
  if (level < 1) level = 1;
  if (level > 5) level = 5;
  return tbl[level - 1];
}

// ── GALA ISRs ─────────────────────────────────────────────────────────────

void galaRising() {
  TIM2->CNT = 0;
  TIM2->CR1 |= TIM_CR1_CEN;
  attachInterrupt(digitalPinToInterrupt(GALA_PIN), galaFalling, FALLING);
}

void galaFalling() {
  TIM2->CR1 &= ~TIM_CR1_CEN;
  gala_captime = (uint16_t)TIM2->CNT;
  attachInterrupt(digitalPinToInterrupt(GALA_PIN), galaRising, RISING);
}

void setup ()
{
  // Load config from flash and apply start volume
  cfg = readConfig();
  uint8_t start_vol = volLevelToHex(cfg.vol);
  volume = current_volume = saved_volume = start_vol;

  volume_packet[0] = 0x02;
  loudness_packet[0] = 0x02;
  volume_packet[1] = 0x02;
  loudness_packet[1] = 0x01;
  Wire.begin (MY_ADDRESS, false, false);
  Wire.onReceive (receiveEvent);
  SWire.begin();

  // Enable SPI1 and AFIO clocks
  RCC->APB2ENR |= RCC_APB2ENR_AFIOEN | RCC_APB2ENR_SPI1EN;
  // Disable JTAG, keep SWD (SWJ_CFG=010) → frees PB3/PB4/PA15 for GPIO; clear SPI1_REMAP → default pins
  AFIO->MAPR = (AFIO->MAPR & ~(AFIO_MAPR_SWJ_CFG | AFIO_MAPR_SPI1_REMAP)) | AFIO_MAPR_SWJ_CFG_JTAGDISABLE;

#ifdef HWV5_BRIDGE
  // ── Bridge mode: STM32 acts AS front panel to radio MCU ──────────────────────────
  // STM32 drives STATUS (PA15) as output; watches CLK (PA5) for byte framing.
  // SPI1 slave with software NSS + RXNE interrupt for byte capture.
  pinMode(mcuCLK, INPUT_PULLUP);   // PA5: SCK from MCU (input)
  attachInterrupt(digitalPinToInterrupt(mcuCLK), mcuClkChange, CHANGE);
  pinMode(mcuDATA, INPUT_PULLUP);  // PA7: MOSI from MCU (input)
  pinMode(mcuSTATUS, OUTPUT);      // PA15: STM32 drives STATUS to MCU (output)
  digitalWrite(mcuSTATUS, HIGH);   // idle HIGH
  pinMode(mcuCS, OUTPUT);          // PA3: hardware-inverted STATUS → PA4/NSS
  digitalWrite(mcuCS, LOW);        // STATUS HIGH → CS LOW
  // SPI1 slave: call SPI.begin() to configure AF pins, then patch to slave mode
  SPI.begin();
  SPI1->CR1 &= ~SPI_CR1_SPE;
  SPI1->CR1 &= ~SPI_CR1_MSTR;
  SPI1->CR1 |= SPI_CR1_SSM | SPI_CR1_SSI; // software NSS, always selected; CPOL=0, CPHA=0
  SPI1->CR1 |= SPI_CR1_SPE;
  SPI1->DR   = 0x00;                       // pre-load MISO idle value
  SPI1->CR2 |= SPI_CR2_RXNEIE;            // fire SPI1_IRQHandler on each received byte
  NVIC_EnableIRQ(SPI1_IRQn);

  // ── Bridge mode: STM32 acts AS radio MCU to front panel ──────────────────────────
  // Panel drives STATUS; STM32 drives CLK (PB13) between packets as GPIO HIGH.
  // SPI2 is only activated inside sendToPanel()/receivePanelPacket().
  pinMode(panelCLK, OUTPUT);
  digitalWrite(panelCLK, HIGH);      // CLK idle HIGH = no transfer in progress
  pinMode(panelSTATUS, INPUT_PULLUP);
  attachInterrupt(digitalPinToInterrupt(panelSTATUS), panelStatusChange, CHANGE);
  pinMode(panelCS, OUTPUT);
  digitalWrite(panelCS, LOW);        // STATUS idle HIGH → CS LOW
#else
  // ── Sniff mode: passive monitoring of MCU↔panel SPI bus ─────────────────────────
  // STATUS ISR gates NSS (PA3→PA4/NSS) to frame each byte.
  pinMode(mcuSTATUS, INPUT_PULLUP);
  pinMode(mcuCS, OUTPUT);
  digitalWrite(mcuCS, !digitalRead(mcuSTATUS));
  attachInterrupt(digitalPinToInterrupt(mcuSTATUS), mcuStatusChange, CHANGE);

  // PA4/NSS, PA5/SCK, PA7/MOSI must be INPUT before enabling SPI1
  pinMode(PA4, INPUT);  // NSS driven via PA3→inverter
  pinMode(PA5, INPUT);
  pinMode(PA7, INPUT);

  // SPI1 slave: SSM=0 → hardware NSS (PA4).  NSS LOW = selected = shift reg active.
  SPI1->CR1 = 0;  // MSTR=0, SSM=0, CPOL=0, CPHA=0
  SPI1->CR1 |= SPI_CR1_SPE;
  SPI1->CR2 = 0;  // no interrupts; loop() polls SR
#endif

  pinMode(displayRESET, INPUT);

  // GALA: TIM2 at 1µs resolution for speed pulse measurement
  if (cfg.gala > 0) {
    pinMode(GALA_PIN, INPUT_PULLDOWN);
    RCC->APB1ENR |= RCC_APB1ENR_TIM2EN;
    TIM2->PSC = 71;       // 72MHz / (71+1) = 1MHz = 1µs ticks
    TIM2->ARR = 0xFFFF;
    TIM2->CNT = 0;
    TIM2->CR1 = 0;        // stopped
    TIM2->EGR = TIM_EGR_UG;  // force update to load PSC/ARR
    attachInterrupt(digitalPinToInterrupt(GALA_PIN), galaRising, RISING);
  }

#ifdef USE_SERIAL
  USEDSERIAL.begin(115200);
  printInfo();
#endif

  set_volume();
}  // end of setup

void printInfo() {
  USEDSERIAL.print(F("Firmware version: "));
  USEDSERIAL.println(F(VERSION));
  USEDSERIAL.println(F("(C) kovo, GPL3"));
  USEDSERIAL.println(F("https://www.tindie.com/products/tomaskovacik/volume-fix-for-audi-concert1chorus1/"));
  USEDSERIAL.println(F("https://github.com/tomaskovacik/audi_concert1_chorus1_volume_fix"));
  // CFG_LOAD: config loaded from flash at startup
  USEDSERIAL.print(F("CFG_LOAD: vol=")); USEDSERIAL.print(cfg.vol);
  USEDSERIAL.print(F(" gala="));        USEDSERIAL.print(cfg.gala);
  USEDSERIAL.print(F(" ta="));          USEDSERIAL.println(cfg.ta);
  if (cfg.gala > 0) {
    USEDSERIAL.print(F("CFG_LOAD: GALA base_thr="));
    USEDSERIAL.print(100 - (cfg.gala - 1) * 15);
    USEDSERIAL.println(F(" km/h"));
  } else {
    USEDSERIAL.println(F("CFG_LOAD: GALA disabled (send g1..g5 to enable)"));
  }
}

void loop()
{
#ifdef USE_SERIAL
  if (USEDSERIAL.available()) {
    char ch = USEDSERIAL.read();
    bool changed = false;
    if (ch == 'v' || ch == 'V' || ch == 'h' || ch == 'H' || ch == '?') {
      printInfo();
    } else if (ch == 's' && USEDSERIAL.available()) {
      uint8_t level = USEDSERIAL.read() - '0';
      if (level >= 1 && level <= 5) { cfg.vol = level; changed = true; }
    } else if (ch == 'g' && USEDSERIAL.available()) {
      uint8_t level = USEDSERIAL.read() - '0';
      if (level <= 5) { cfg.gala = level; changed = true; }
    }
    if (changed) {
      if (writeConfig(cfg)) {
        USEDSERIAL.println(F("Config saved. Restart to apply."));
      } else {
        USEDSERIAL.println(F("Config write FAILED."));
      }
      printInfo();
    }
  }
#endif

  // displayRESET edge: reload start volume from config when radio panel wakes up
  bool reset_high = digitalRead(displayRESET);
  if (reset_high && !displayRESETstate) {
    displayRESETstate = true;
    uint8_t start_vol = volLevelToHex(cfg.vol);
    volume = current_volume = saved_volume = start_vol;
#ifdef USE_SERIAL
    USEDSERIAL.println(F("Reset HIGH — reloaded start volume"));
#endif
  }
  if (!reset_high && displayRESETstate) {
    displayRESETstate = false;
  }

#ifdef HWV5_BRIDGE
  // ── SPI bridge forwarding ────────────────────────────────────────────────────────
  // Panel-initiated button press: panelStatusChange ISR detected STATUS FALLING
  // with CLK HIGH and already drove CLK LOW. Complete byte exchange here.
  if (panel_wants_to_send && !panel_grabbing_SPI) {
    receivePanelPacket();
  }

  // MCU→panel display forward: send queued bytes to panel via SPI2.
  if (!panel_grabbing_SPI && !mcu_to_panel.empty()) {
    sendToPanel();
  }

  // Panel→MCU button forwarding: signal MCU (drive STATUS LOW while CLK HIGH),
  // then SPI1 clocks out the pre-loaded button byte via MISO.
  if (!grabbing_SPI && !mcu_read_initiated && !panel_to_mcu.empty()) {
    uint8_t tx;
    if (panel_to_mcu.pop(tx)) {
      noInterrupts();
      SPI1->DR = tx;
      mcu_read_initiated = 1;
      digitalWrite(mcuCS, HIGH);
      digitalWrite(mcuSTATUS, LOW);   // "panel has data" interrupt to MCU
      interrupts();
      uint32_t t = micros();
      while (!grabbing_SPI && (micros() - t) < 5000);
      if (!grabbing_SPI) {
        mcu_read_initiated = 0;
        SPI1->DR = 0x00;
        digitalWrite(mcuSTATUS, HIGH);
        digitalWrite(mcuCS, LOW);
      }
    }
  }
#endif

#ifdef HWV5_BRIDGE
  if (!grabbing_SPI) {
    while (drdp != dwdp) {
      uint8_t _data[howmanybytesinpacket];
      for (uint8_t i = 0; i < howmanybytesinpacket; i++) _data[i] = _msg[drdp][i];
#ifdef USE_SERIAL
      if (_data[0] == 0x25) {
        USEDSERIAL.print(F("BTN "));
        USEDSERIAL.println(_data[1], HEX);
      }
#endif
      if (_data[0] == 0x25) {
        if (grab_volume && (_data[1] == PANEL_KNOB_UP || _data[1] == PANEL_REMOTE_VOLUME_UP)) {
          set_volume_up();
          set_volume();
        }
        if (grab_volume && (_data[1] == PANEL_KNOB_DOWN || _data[1] == PANEL_REMOTE_VOLUME_DOWN)) {
          set_volume_down();
          set_volume();
        }
      }
      if (_data[0] == 0x9A) {
        decode_display_data(_data);
      }
      drdp++; if (drdp == howmanypackets) drdp = 0;
    }
  }
#else
  if (!panel_message.busy) {
    while (panel_message.available()) {
      uint8_t _data[howmanybytesinpacket];
      panel_message.read(_data);
#ifdef USE_SERIAL
      if (_data[0] == 0x25) {
        USEDSERIAL.print(F("BTN "));
        USEDSERIAL.println(_data[1], HEX);
      }
#endif
      if (_data[0] == 0x25) {
        if (grab_volume && (_data[1] == PANEL_KNOB_UP || _data[1] == PANEL_REMOTE_VOLUME_UP)) {
          set_volume_up();
          set_volume();
        }
        if (grab_volume && (_data[1] == PANEL_KNOB_DOWN || _data[1] == PANEL_REMOTE_VOLUME_DOWN)) {
          set_volume_down();
          set_volume();
        }
      }
      if (_data[0] == 0x9A) {
        decode_display_data(_data);
      }

    }
  }
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

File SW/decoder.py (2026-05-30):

#!/usr/bin/env python3
"""
Audi Concert1 / Chorus1 — serial decoder
Reads SPI/BTN/I2C lines from the STM32 volume-fix firmware and decodes them.

Usage:
  python3 decoder.py /dev/ttyUSB0          # default 115200
  python3 decoder.py /dev/ttyUSB0 9600
  python3 decoder.py --stdin               # pipe from file / socat
  python3 decoder.py --debug /dev/ttyUSB0  # append raw hex to every line
  python3 decoder.py --debug --stdin       # debug from stdin
"""

import sys
import re

# ── ANSI colours ─────────────────────────────────────────────────────────────
R  = "\033[91m"   # red    – buttons / knob
G  = "\033[92m"   # green  – volume / loudness
Y  = "\033[93m"   # yellow – display text / LEDs
B  = "\033[94m"   # blue   – I2C
C  = "\033[96m"   # cyan   – SPI raw
M  = "\033[95m"   # magenta – GALA speed
RST = "\033[0m"

# ── Panel button map (from audi_concert_panel.h) ─────────────────────────────
BUTTONS = {
    0x01: "1",            0x02: "2",            0x03: "3",
    0x04: "4",            0x05: "5",            0x06: "6",
    0x07: "SEEK_UP / NEXT_CD",
    0x08: "TP",           0x09: "RDS",          0x0A: "CPS",
    0x0B: "MODE",         0x0C: "RD",
    0x0D: "PREV_TRACK / FAST_REWIND",
    0x0E: "FADE",         0x0F: "BALANCE",      0x10: "BASS",
    0x11: "AM",           0x12: "DOLBY",
    0x13: "FAST_FWD / NEXT_TRACK",
    0x14: "TREBLE",       0x15: "AS",           0x16: "SCAN",
    0x17: "FM",
    0x18: "SEEK_DOWN / PREV_CD",
    0x19: "REVERSE",
    0x1A: "REMOTE_VOL_UP",   0x1B: "REMOTE_VOL_DOWN",
    0x1C: "REMOTE_UP",       0x1D: "REMOTE_DOWN",
    0x1E: "CODE_IN",          0x1F: "EJECT",
    0x21: "BUTTON_RELEASE",
    0x25: "PANEL_START",
    0x26: "REMOTE_LEFT",      0x27: "REMOTE_RIGHT",
    0x86: "KNOB_UP",          0x88: "KNOB_DOWN",
}

# ── SPI packet decode (0x9A packets from MC68HC05 → ST6280) ──────────────────
BASS_TABLE = {
    0:  -14, 1: -12, 2: -10, 3: -8, 4: -6, 5: -4, 6: -2,
    7:    0, 8:  14, 9:  12, 10: 10, 11: 8, 12: 6, 13: 4, 14: 2, 15: 0,
}

def decode_spi(d):
    sub = d[1]
    lines = []
    raw = ' '.join(f'{b:02X}' for b in d)

    if sub == 0x13:  # LED indicators
        b2, b3, b4 = d[2], d[3], d[4]
        leds = []
        # byte 2: [nan|FM2|FM1|FM|AS|RDS|REG] (bit 3 = FM band present)
        if b2 & 0x01: leds.append("REG")
        if b2 & 0x02: leds.append("RDS")
        if b2 & 0x04: leds.append("AS")
        if b2 & 0x08:
            if b2 & 0x40: leds.append("FM1")
            if b2 & 0x20: leds.append("FM2")
            if b2 & 0x10: leds.append("AM")
        # byte 2 unknown bits
        if b2 & 0x80: leds.append("b2.7?")
        # byte 3: [?|?|CPS|RD|?|?|presets(2b)]
        mem = b3 & 0x03
        if b3 & 0x04: leds.append("b3.2?")
        if b3 & 0x08: leds.append("b3.3?")   # was wrongly "CPS" — actual meaning unknown
        if b3 & 0x10: leds.append("RD")
        if b3 & 0x20: leds.append("CPS")      # confirmed: lights when CPS active
        if b3 & 0x40: leds.append("b3.6?")
        if b3 & 0x80: leds.append("b3.7?")
        # byte 4: [nan|MODE|AS|SCAN|FM|TP|AM|RDS]
        if b4 & 0x01: leds.append("RDS-led")
        if b4 & 0x02: leds.append("AM-led")
        if b4 & 0x04: leds.append("TP-led")
        if b4 & 0x08: leds.append("FM-led")
        if b4 & 0x10: leds.append("SCAN-led")
        if b4 & 0x20: leds.append("AS-led")
        if b4 & 0x40: leds.append("MODE-led")
        if b4 & 0x80: leds.append("b4.7?")
        lines.append(f"LEDs: {' '.join(leds) or 'none'}  MEM={mem}  [{raw}]")

    elif sub == 0x23:
        lines.append("Display CLEAR")

    elif sub == 0x32:  # AM/FM frequency
        if d[3] == 0x10:
            freq = 531 + d[2] * 9
            lines.append(f"Freq: {freq} kHz (AM)")
        else:
            freq = (875 + d[2]) / 10.0
            lines.append(f"Freq: {freq:.1f} MHz (FM)")

    elif sub == 0x48:  # ASCII display text
        text = ''.join(chr(b) if 0x20 <= b < 0x7F else '.' for b in d[2:])
        lines.append(f"Display: \"{text.rstrip()}\"")

    elif sub == 0x58:  # settings menu text
        text = ''.join(chr(b) if 0x20 <= b < 0x7F else '.' for b in d[2:10])
        lines.append(f"Settings: \"{text.rstrip()}\"")

    elif sub == 0x61:  # status/mode display (tape, AS-store, SAFE, DIAG, BOSE…)
        status = {
            0x00: "Tape: Eject",
            0x01: "Tape: Play ▲",
            0x02: "Tape: Play ▼",
            0x03: "Tape: FF →→",
            0x04: "Tape: RW ←←",
            0x05: "CONNECT",
            0x07: "NO CDC",
            0x0B: "SAFE",
            0x10: "TP-INFO",
            0x13: "AS-STORE",
            0x14: "DIAG",
            0x17: "Unknown-0x17",
            0x1A: "BOSE",
        }
        lines.append(f"Status: {status.get(d[2], f'0x{d[2]:02X}')}")

    elif sub == 0x71:  # BAS/TRE/BAL/FAD stored value
        hi = d[2] >> 4
        lo = d[2] & 0x0F
        names = {0: "BAS+", 1: "BAS-", 2: "TRE+", 3: "TRE-",
                 4: "BAL-R", 5: "BAL-L", 6: "FAD-F", 7: "FAD-R",
                 0xA: "TP-MEM", 0xB: "GALA"}
        label = names.get(hi, f"0x{hi:X}")
        lines.append(f"{label}: {lo}")

    elif sub == 0x80:
        if d[2] == 0x00:
            lines.append("Shutdown")
        else:
            lines.append(f"Power: 0x{d[2]:02X}")

    elif sub == 0x92:
        lines.append(f"Safe code: {d[2]:02X}{d[3]:02X}")

    elif sub == 0xA2:  # CD changer
        lines.append(f"CD {d[2]:X}  Track {d[3]:X}")

    elif sub == 0xE1:
        # Panel lifecycle states — ST6280 OTP firmware, empirically observed.
        # Upper nibble always 0xF; lower nibble appears to be active-low status flags.
        states = {
            0xFF: "Panel idle / sleep",
            0xFE: "Panel HW init",
            0xFC: "Panel display init",
            0xFB: "Panel START (app ready)",
        }
        label = states.get(d[2], f"Panel state 0x{d[2]:02X}")
        lines.append(label)

    else:
        lines.append(f"Unknown sub=0x{sub:02X}")

    return lines


# ── I2C packet decode (TDA7342) ───────────────────────────────────────────────
def spk_atten(c):
    if (c & 0x1F) == 0x1F:
        return "Muted"
    low  = (c & 0x07) * 1.25
    high = ((c >> 3) & 0x03) * 10
    return f"{-(low + high):.2f} dB"
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

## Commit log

2018-09-21 HW part
    [audi_concert1_chorus1_volume_fix.csv, audi_concert1_chorus1_volume_fix.kicad_pcb, audi_concert1_chorus1_volume_fix.sch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]
2018-12-29 gerber filesgerbers/
    [audi_concert1_chorus1_volume_fix-B.Cu.gbr, audi_concert1_chorus1_volume_fix-B.Fab.gbr, audi_concert1_chorus1_volume_fix-B.Mask.gbr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]
2019-01-02 v2.0 files
    [audi_concert1_chorus1_volume_fix.csv, audi_concert1_chorus1_volume_fix.kicad_pcb, audi_concert1_chorus1_volume_fix.sch]
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2019-01-06 fix assemble plan for 1.0boards
2019-03-16 do not reset saved_volume to start_volume value
    [audi_volume_fix_stm32.ino]
2019-03-16 try fix #3
    logic: send mute data only if volume is 0xFF
    [audi_volume_fix_stm32.ino]
2019-03-22 Revert "try fix #3"
    This reverts commit 25e89c3670227bfe58622b0d499b7f2911ed3e48.
    [audi_volume_fix_stm32.ino]
2019-03-24 remove unused hw
    [audi_concert1_chorus1_volume_fix.csv, audi_concert1_chorus1_volume_fix.kicad_pcb, audi_concert1_chorus1_volume_fix.sch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]
2019-03-24 move hw files
    [audi_concert1_chorus1_volume_fix-B.Cu.gbr, audi_concert1_chorus1_volume_fix-B.Fab.gbr, audi_concert1_chorus1_volume_fix-B.Mask.gbr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]
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2020-04-11 hw v2
    [audi_concert1_chorus1_volume_fix_v2.kicad_pcb]
2020-04-11 HW v3
    [audi_concert1_chorus1_volume_fix.kicad_pcb, audi_concert1_chorus1_volume_fix.sch]
2020-04-11 misc files
    [audi_concert1_chorus1_volume_fix_v2.csv]
2020-04-11 cleanup in HW files
    [audi_concert1_chorus1_volume_fix-B.Cu.gbr, audi_concert1_chorus1_volume_fix.drl]
2020-04-12 silk screen positioning
    [audi_concert1_chorus1_volume_fix.kicad_pcb]
2020-05-14 hw v3 - buggy
    [audi_concert1_chorus1_volume_fix_v3.kicad_pcb, audi_concert1_chorus1_volume_fix_v3.kicad_sch]
2020-05-14 hw v4
    [audi_concert1_chorus1_volume_fix.kicad_pcb, audi_concert1_chorus1_volume_fix.kicad_sch]
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2020-05-15 change pin define for RESET back to displayRESET, it is not split because line has no resistor inline between mcu and display
    [audi_volume_fix_stm32.ino]
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2020-09-16 schematics, pcb and assemble plan for v4 in case of v1 code is used
    [audi_concert1_chorus1_volume_fix_v4_for_v1_code.kicad_pcb, audi_concert1_chorus1_volume_fix_v4_for_v1_code.kicad_sch]
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2020-09-16 minor changes
    [audi_concert1_chorus1_volume_fix_v1.kicad_pcb]
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2020-09-16 bump version in schematics to 4.0
    [audi_concert1_chorus1_volume_fix.kicad_sch]
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2020-12-16 fix resistors are 0805
    [audi_concert1_chorus1_volume_fix_v3.kicad_sch]
2020-12-17 fix for v3 HW
    [audi_concert1_chorus1_volume_fix_v3.kicad_pcb]
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2021-07-17 hw changes
    [audi_concert1_chorus1_volume_fix_v4_for_v1_code.kicad_pcb, audi_concert1_chorus1_volume_fix_v4_for_v1_code.kicad_sch]
2021-09-06 vias changed to 0.5/0.3
    [audi_concert1_chorus1_volume_fix.kicad_pcb]
2021-09-06 gala input fix 11+10 togeter
    [audi_concert1_chorus1_volume_fix.kicad_sch]
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2021-10-25 fix of fix, forgot that i am callig delay() on more then one place, which was sleeping mcu in not good places
    [audi_volume_fix_stm32.ino]
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2021-11-14 HW v5
    [audi_concert1_chorus1_volume_fix.kicad_pcb, audi_concert1_chorus1_volume_fix.kicad_sch]
2021-11-14 HWv5 fix
    [audi_concert1_chorus1_volume_fix.kicad_pcb]
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2022-05-09 new version kicad
    [audi_concert1_chorus1_volume_fix.kicad_sch]
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2026-05-10 Replace SlowSoftWire with FlexWire for I2C
    [audi_volume_fix_stm32.ino]
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2026-05-12 add CircularPacketBuffer struct with read/write/commit/available; replace raw arrays with panel_message and i2c_data objects
    Agent-Logs-Url: https://github.com/tomaskovacik/audi_concert1_chorus1_volume_fix/sessions/af5f186a-f925-4d40-ab33-d41c73154ec0
    [audi_volume_fix_stm32.ino]
2026-05-12 address review feedback: busy→bool, split write() post-increment, fix typo
    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
    [audi_volume_fix_stm32.ino]
2026-05-14 Remove Wire_slave library from compile.yml
    Removed 'Wire_slave' library from the workflow configuration, it is part of stm32duino
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2026-05-16 Fix STM32 workflow install
2026-05-16 fix: use dedicated volume recalc flag to suppress spurious mute
    Agent-Logs-Url: https://github.com/tomaskovacik/audi_concert1_chorus1_volume_fix/sessions/8522ce3f-b7ca-4807-b6a5-26b2c527c888
    [audi_volume_fix_stm32.ino]
2026-05-16 HW update
    [audi_concert1_chorus1_volume_fix.kicad_pcb, audi_concert1_chorus1_volume_fix.kicad_sch]
2026-05-25 feat: replace bit-bang SPI sniffing with HW SPI1 slave for HWV5
    STM32 now acts as SPI1 slave toward the Audi radio MCU instead of
    passively bit-banging CLK/DATA via STATUS interrupts.
    - mcuDATA: PA6 → PA7 (SPI1_MOSI; PA6 was used in bit-bang mode)
    - mcuCS PA3 added (hw-inverted PA15, mirrors !STATUS)
    - setup(): STATUS driven OUTPUT; CLK CHANGE interrupt → mcuClkChange()
    SPI1 configured as slave (SSM/SSI, MODE 0, RXNE IRQ)
    - mcuClkChange(): CLK-edge state machine driving STATUS handshake
    - spi1ByteReceived() + SPI1_IRQHandler: RXNE path stores bytes into
    panel_message CircularPacketBuffer
    [audi_volume_fix_stm32.ino]
2026-05-25 fix: use libmaple register API for SPI1 slave (Roger Clark stm32duino)
    In Roger Clark's STM32F1 core, SPI1 is spi_dev* so registers live at
    SPI1->regs->CR1/CR2/SR/DR, not SPI1->CR1 (which is the CMSIS/HAL layout).
    Likewise NVIC uses nvic_irq_enable(NVIC_SPI1) and the vector table entry
    for the interrupt is the weak symbol __irq_spi1, not SPI1_IRQHandler.
    All constants (SPI_CR1_SPE/MSTR/SSM/SSI, SPI_CR2_RXNEIE, SPI_SR_RXNE)
    are already defined in libmaple's spi.h so no changes needed there.
    [audi_volume_fix_stm32.ino]
2026-05-25 fix(HWSPI): convert to passive SPI1 sniffing (not man-in-the-middle)
    HWv5 is a passive sniffer identical in role to HWv1-v4: MCU drives CLK
    and DATA, panel drives STATUS, STM32 only observes. Previous commits
    wrongly implemented man-in-the-middle (STM32 driving STATUS/CS).
    Changes:
    - mcuSTATUS → INPUT_PULLUP; STATUS RISING → enableInterruptOnCLK
    - Remove mcuCS (PA3) define and all digitalWrite(mcuSTATUS/CS) calls
    - PA5/PA7 restored to INPUT_PULLUP after SPI.begin() (which sets them
    AF_OUTPUT_PP for master mode)
    - __irq_spi1: only captures _byte = DR; no STATUS toggling
    - enableInterruptOnCLK CLK-LOW branch: reset SPI1 shift register for
    byte alignment instead of attaching readCLK G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
    [audi_volume_fix_stm32.ino]
2026-05-25 debug: add passive SPI1 diagnostic counters and simplified serial output
    Five volatile counters (STATUS RISING CLK-H/L, STATUS FALLING, SPI RXNE,
    last byte) incremented from ISRs; loop() prints a one-liner on any change.
    Startup message "HWV5 passive SPI1 ready" after Serial.begin().
    decode_display_data and decode_button_push wrapped in if(false) so the
    screen stays readable; replaced with raw hex dumps ("SPI: xx xx ..." and
    "BTN: 0xNN") for the debug session.
    [audi_volume_fix_stm32.ino]
2026-05-25 fix(HWSPI): mirror STATUS→PA3→NSS, hardware NSS, fix GPIO before SPE
    Root cause of RXNE=0: SPI.begin() leaves PA5/PA7 as AF_OUTPUT_PP while
    STM32 is in slave mode, fighting the external CLK/DATA signals; SPI1
    saw no clean edges.
    Fixes:
    - STATUS CHANGE ISR (mcuStatusChange) mirrors STATUS to PA3; hardware
    inverter on PCB routes PA3→SPI1_NSS(PA4), giving a per-byte NSS pulse
    that resets the SPI1 shift register automatically — no software reset.
    - SPI1 switched to SSM=0 (hardware NSS via PA4).
    - gpio_set_mode(PA4/5/7, INPUT_FLOATING) called BEFORE SPI_CR1_SPE=1,
    so SPI1 is enabled only after SCK/MOSI/NSS pins are proper inputs.
    - mcuCS (PA3) re-added as output; initialized to mat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
    [audi_volume_fix_stm32.ino]
2026-05-25 hwv5: simplify to pure passive SPI1 sniffer with loop() polling
    - Replace SPI.begin() with direct RCC APB2ENR raw register write to
    ensure SPI1 clock is actually enabled (SPI.begin() may target SPI2).
    - Clear AFIO SPI1_REMAP so SPI1 uses default pins PA4-PA7.
    - Use SSM=1/SSI=1 (always-selected slave), no NSS pin or PA3 needed.
    CR2=0: no interrupts, loop() polls SR.RXNE directly.
    - mcuStatusChange reduced to packet framing only (busy/commit +
    debug counters), no PA3/NSS I/O.
    - loop() reads DR on RXNE, writes byte to panel_message when busy.
    - Startup diagnostic prints CR1/CR2/AFIO values so missing RCC clock
    is immediately visible (CR1=0 → clock off).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
    [audi_volume_fix_stm32.ino]
2026-05-25 hwv5: fix SSI=0 so SPI1 slave is actually selected
    SSM=1/SSI=1 forces internal NSS HIGH which DESELECTS the slave —
    that is the master-mode MODF-prevention pattern, not slave init.
    Slave must use SSM=1/SSI=0 (NSS forced LOW = always selected).
    This is why RXNE was perpetually 0 despite CLK edges on PA5.
    [audi_volume_fix_stm32.ino]
2026-05-25 hwv5: add Makefile for arduino-builder CLI build+upload; add PKT debug
    Makefile wraps the exact arduino-builder command extracted from the IDE's
    -dump-prefs output. `make` compiles and uploads via STLink in one shot.
    `make serial` opens picocom. `make clean` wipes the build cache.
    PKT 0x.. line printed for every committed panel_message packet so we can
    see whether 0x25 (knob) and 0x9A (display) frames are being received.
2026-05-25 hwv5: switch to NSS hardware gating (SSM=0) to fix byte alignment
    Always-selected (SSM=1) lets SPI1 count stray CLK edges between packets
    where CLK idles HIGH, rotating all received bytes by 1+ bits. SW SPI was
    immune because enableInterruptOnCLK/disableInterruptOnCLK only counted
    CLK edges inside the STATUS HIGH window — exactly what hardware NSS does.
    Fix: SSM=0, PA3→PCB inverter→PA4/NSS mirrors STATUS signal:
    STATUS HIGH (byte active) → NSS LOW → SPI1 shift reg active (8 edges)
    STATUS LOW (byte done) → NSS HIGH → SPI1 shift reg resets to bit-0
    Now that RCC is enabled via raw register (not SPI.begin()), hardware NSS
    should finally work and produce correctly-framed b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
    [audi_volume_fix_stm32.ino]
2026-05-25 fix: data from SPI byte 2 packet
    [audi_volume_fix_stm32.ino]
2026-05-25 Add Python decoder, fix Makefile, restore USEDSERIAL.begin()
    - SW/decoder.py: new Python serial decoder replacing in-firmware decoding
    - Decodes SPI packets, BTN presses, I2C TDA7342 commands
    - Clean output: decoded text only, hex fallback for unknowns
    - Reads from /dev/ttyUSB0 or --stdin
    - Makefile: split build/upload targets, add st-flash STLink upload,
    serial target calls decoder.py, remove -DSERIAL_USB to save ~1.9KB
    - audi_volume_fix_stm32.ino: restore USEDSERIAL.begin(115200) in setup()
    accidentally dropped during cleanup; also move printInfo() call here
    [audi_volume_fix_stm32.ino, decoder.py]
2026-05-25 Clean up commented-out code and verbose comments
    Remove dead code: SW I2C Arduino block, old pin defines, TwoWire
    attempt, commented debug prints, large decode_i2c/spk_atten block
    (moved to decoder.py). Trim verbose inline comments to essentials.
2026-05-25 Update README BOM link to v5; add buffer overflow guards
    - README: update assemble plan link from v4 to v5 ibom
    - CircularPacketBuffer::commit(): check for full buffer before
    advancing wdp to avoid silently overwriting unread packets
    - receiveEvent(): clamp howMany to avoid writing past packet boundary
    [audi_volume_fix_stm32.ino]
2026-05-25 Remove HW version ifdefs; keep HWv5-only code paths
    - Delete #define HWV5 and all #ifdef HWV3/HWV4/HWV5 conditionals
    - Keep only HWv5 pins: mcuCLK=PA5, mcuDATA=PA7, mcuCS=PA3, mcuSTATUS=PA15, displayRESET=PB8
    - Remove SW bit-bang SPI dead code: enableInterruptOnCLK(), disableInterruptOnCLK(), readCLK()
    - Remove _byte global (used only by removed SW SPI path)
    - Remove decode_i2c() forward declaration (body already removed)
    - Remove unused displayRESETstate variable
    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
2026-05-25 Micro-optimisations: -112 bytes flash
    - CircularPacketBuffer::read(): remove redundant zero-fill (commit() already zeros on write)
    - set_volume(): deduplicate ramp step tail (volume_packet/set_loudness/sendI2C shared)
    - set_mute/set_unmute: make payload arrays static const (off stack, in flash)
    - sendI2C: take const pointer (correctness, enables passing const arrays)
    - mute/in_volume_recalc: volatile bool instead of volatile uint8_t
    [audi_volume_fix_stm32.ino]
2026-05-25 Port STM32 HWv5 code to AVR (ATmega328P)
    Replace old unfinished AVR sketch with a direct port of the clean
    STM32 master code. Logic is identical; only hardware-specific parts
    change:
    - Pins: STM32 PA/PB → AVR numeric (STATUS=2/INT0, CLK=13/SCK,
    DATA=11/MOSI, CS=10/SS, RESET=8, SWire on A2/A3)
    - SPI slave init: STM32 SPI1 registers → AVR SPCR=(1<<SPE)
    - Byte harvest: SPI1 DR/SR → SPDR/SPSR in mcuStatusChange ISR
    - Wire slave: Wire_slave.h/FlexWire → Wire.h + SlowSoftWire(A2,A3)
    - Serial: Serial1 → Serial
    - Lookup tables use PROGMEM to save 58 bytes SRAM
    - Add Makefile targeting Arduino Nano (ATmega328P, arduino-builder)
    Build result: 6196 B flash (20%), 1129 B SRAM (55%)
    Co-au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
    [audi_volume_fix_avrPB.ino]
2026-05-26 AVR: replace SlowSoftWire with FlexWire
    FlexWire has native AVR optimisation (util/atomic, port-register
    bit-bang) giving slightly lower SRAM usage (1116 vs 1129 bytes)
    and matches the library already used in the STM32 build.
    [audi_volume_fix_avrPB.ino]
2026-05-27 decoder.py: fix 0x61 packet — add AS-STORE (0x13), rename TAPE→Status
    Packet 0x61 is used for multiple status modes, not just tape.
    - Rename 'TAPE:' label to 'Status:' with Tape: prefix for actual tape states
    - Add 0x13 = AS-STORE (observed while radio runs autoselect store)
    - Add 0x17 = Unknown-0x17 (seen in original logs, still undecoded)
    - Fix key format: use explicit 0xNN hex keys for all entries
    [decoder.py]
2026-05-27 decoder.py: fix LED decode, expose unknown bits, append raw hex
    - Fix CPS/Dolby swap: b3 bit 5 (0x20) is CPS (confirmed), not Dolby
    - b3 bit 3 (0x08) was wrongly labeled CPS, now shown as b3.3?
    - Expose all unknown b2/b3/b4 bits as bN.M? so Dolby LED location
    can be identified from live traffic
    - Append raw hex [XX XX ...] to every decoded SPI line for reference;
    0x13 LED lines embed it inline, all others get it as suffix
    [decoder.py]
2026-05-27 decoder.py: make hex dump opt-in via --debug flag
    Without --debug: clean decoded output only.
    With --debug: raw hex [XX XX ...] appended to every line (SPI, BTN, I2C).
    --debug can be placed anywhere in the argument list:
    python3 decoder.py --debug /dev/ttyUSB0
    python3 decoder.py --debug --stdin
2026-05-27 Add EEPROM config and GALA speed-based volume
    EEPROM (single 1KB flash page, no wear-levelling library):
    - Config struct: vol (1-5 start volume level), gala (0=off 1-5 speed
    sensitivity), ta (reserved), CRC, magic bytes
    - readConfig()/writeConfig() use raw FLASH_ErasePage/ProgramHalfWord
    from flash_stm32.c (bundled from Roger Clark EEPROM library)
    - flash_stm32.h/c added to sketch directory for self-contained build
    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
2026-05-27 eeprom-gala: clean up globals, remove flash reads from loop()
    - Replace start_volume/start_loudness temporaries with direct init
    - Add global Config cfg loaded once in setup(); remove all readConfig()
    calls from loop() (previously flash-reading on every iteration in the
    GALA block)
    - Serial command handler modifies cfg in-place before writeConfig()
    - displayRESET handler uses global cfg (no extra flash read)
    - grab_volume and displayRESETstate changed to bool
    - Trim decode_display_data comment block to compact form
    - Remove redundant set_mute/set_unmute function comments
    Build: 23464 bytes (71%) flash, 2672 bytes (26%) SRAM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
    [audi_volume_fix_stm32.ino]
2026-05-27 eeprom-gala: auto-save config from radio settings menu display
    When user navigates the radio's built-in settings menu (SET+SEK),
    the panel sends 0x9A/0x58 packets with ASCII text like:
    "VOL 3 " -> cfg.vol = 3
    "TA 2 " -> cfg.ta = 2
    "GALA 1 " -> cfg.gala = 1
    "GALA OFF" -> cfg.gala = 0
    Sniff these strings in decode_display_data() and persist immediately
    via writeConfig() so no serial connection is needed to configure.
    Ported from config2EEPROM branch with two bug fixes:
    - GALA numeric/OFF cases called saveVolEeprom instead of saveGalaEeprom
    - GALA OFF check compared _data[9] to 'F' twice (same index); fixed to
    check _data[7]=='O' && _data[8]=='F' && _data[9]=='F'
    Co-authored-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
    [audi_volume_fix_stm32.ino]
2026-05-27 eeprom-gala: expand short variable names for readability
    sv -> start_vol
    lvl -> level
    rst -> reset_high
    ct -> pulse_width_us
    cur_speed -> speed_kmh
    thr -> base_speed_thr
    v_thr -> vol_speed_thr
    l_thr -> loud_speed_thr
    step -> band
    l -> loud_calc
    src/addr -> src_words/flash_addr
    [audi_volume_fix_stm32.ino]
2026-05-27 eeprom-gala: add serial debug output for config/GALA events
    Prefixes (all guarded by USE_SERIAL):
    CFG_LOAD: config read from flash at startup (vol/gala/ta + base_thr)
    CFG_PANEL: config value parsed from display 0x58 packet (before save)
    CFG_SAVE: writeConfig result OK/FAIL with vol/gala/ta values
    GALA_SPEED: speed change prev->new km/h with base threshold
    GALA_VOL: volume step UP/DOWN with band, threshold, new vol hex
    GALA_LOUD: loudness step UP/DOWN with band, threshold, new loudness hex
    [audi_volume_fix_stm32.ino]
2026-05-27 eeprom-gala: clamp config fields to valid range after CRC check
    If flash partially corrupts but CRC still passes, each field is
    clamped to its valid range instead of using a corrupt value:
    vol: 1-5 → DEFAULT_VOL if out of range
    gala: 0-5 → DEFAULT_GALA if out of range
    ta: 1-5 → DEFAULT_TA if out of range
2026-05-27 feature/eeprom-gala-isr: GALA pulse-timing ISR on PB5 with averaging
    - GALA input: PB5 (TIM3_CH2, tied with PB4/TIM3_CH1), INPUT_PULLDOWN
    BC558 PNP high-side driver, parallel with HC05 pin23 via 1kΩ
    - JTAG disabled in AFIO_MAPR (SWJ_CFG=010) to free PB3/PB4/PB5 as GPIO
    - ISR: galaRising() resets/starts Timer2, galaFalling() captures pulse width
    Timer2 at 1µs resolution (72MHz / prescaler 72)
    - 8-sample rolling average of pulse_us to suppress ±1µs jitter
    - Speed formula: km/h = 1000000 / (2 × avg_pulse_us)
    - Startup volume table: { 0xC2, 0xBE, 0xBA, 0xB6, 0xB2 } (middle=0xBA)
    - Serial: outgoing TDA7342 traffic printed as 'TDA' prefix (incoming disabled)
    - decoder.py: TDA, GALA_SPEED,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
    [audi_volume_fix_stm32.ino, decoder.py]
2026-05-28 Port firmware to official STMicroelectronics STM32 Arduino core
    Replace all libmaple/Roger-Clark-core-specific APIs:
    - Wire_slave.h + FlexWire.h → Wire.h (official core slave support)
    - FlexWire SWire(PB11,PB10) → TwoWire SWire(PB11,PB10) (HW I2C2)
    - flash_stm32.h + FLASH_Unlock/ErasePage/ProgramHalfWord/Lock →
    HAL_FLASH_Unlock/HAL_FLASHEx_Erase/HAL_FLASH_Program/HAL_FLASH_Lock
    - Timer2.setPrescaleFactor/setOverflow/pause/resume/setCount/getCount →
    direct TIM2 CMSIS registers (RCC APB1, PSC/ARR/CNT/CR1/EGR)
    - gpio_set_mode(GPIOA, N, GPIO_INPUT_FLOATING) → pinMode(PAn, INPUT)
    - SPI1->regs->CR1/CR2/SR/DR → SPI1->CR1/CR2/SR/DR (no regs wrapper)
    - Raw RCC/AFIO addresses → CMSIS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
    [audi_volume_fix_stm32.ino]
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2026-05-30 Makefile: use xpack-openocd for upload via ST-Link
    Replace st-flash with OpenOCD (bundled with STM32 core 2.12.0):
    interface/stlink.cfg + board/stm32f103c8_blue_pill.cfg
    program + verify + reset
2026-05-30 fix: replace hardware I2C2 with FlexWire software I2C for TDA7342
    STM32F103C6 only has I2C1 — using TwoWire(PB11,PB10) was trying to
    instantiate non-existent I2C2, causing I2C_ERR 4 on every transmission.
    Replace with FlexWire (software I2C) on PB11/PB10, same as the original
    libmaple-based code. Also move Config struct into audi_concert_panel.h
    to fix Arduino prototype injection ordering issue.
    [audi_volume_fix_stm32.ino]
2026-05-30 docs: update README for official STM32 core, correct build instructions
    - Update branch table to feature/eeprom-gala-isr-STM32CORE
    - Replace Roger's core with official STMicroelectronics core 2.12+
    - Document FlexWire dependency
    - Fix make targets (upload/serial/clean)
    - Note OpenOCD replaces st-flash
    - Fix TDA prefix in decoder output table
2026-05-31 ci: switch to official STMicroelectronics STM32 core
    Replace Roger Clark's stm32duino:STM32F1 with official STMicroelectronics
    core (FQBN: STMicroelectronics:stm32:GenF1:pnum=BLUEPILL_F103C6,opt=osstd).
    Remove EEPROM library dep (HAL flash is built into the core).
    Keep FlexWire for software I2C.
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2026-08-05 Fix ambiguous Wire.begin() overload with official STM32 core
    TwoWire::begin(uint8_t) and begin(uint8_t, bool, bool) both match a
    single-argument call, so newer core versions reject it as ambiguous.
    Pass all three args explicitly to disambiguate.
    [audi_volume_fix_stm32.ino]
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2026-08-06 Rebase dual-SPI bridge onto master + fix for official STM32 core
    Integrates HWV5 man-in-the-middle bridge code into the current master.
    The bridge is activated by #define HWV5_BRIDGE; omitting it gives the
    passive-sniff master firmware.
    Changes vs old dual-spi-panel-bridge base:
    - Wire_slave.h → Wire.h (already in master via STM32CORE port)
    - TwoWire SWire(2, I2C_FAST_MODE) → FlexWire (already in master)
    - SPIClass SPI_2(2) → SPIClass SPI_2(PB15, PB14, PB13) (official core)
    - Remove __attribute__((interrupt("IRQ"))) from SPI1_IRQHandler (libmaple-ism)
    - All master improvements included: GALA, flash config, official STM32 core,
    FlexWire I2C, CircularPacketBuffer, EEPROM-free config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
    [audi_volume_fix_stm32.ino]
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2026-08-06 Fix SPIClass::setBitOrder/setDataMode removed in official STM32 core
    The STM32duino SPI library dropped these legacy setters; begin()
    already applies MSBFIRST/SPI_MODE0 by default, so drop the now
    invalid, redundant calls.
    [audi_volume_fix_stm32.ino]
